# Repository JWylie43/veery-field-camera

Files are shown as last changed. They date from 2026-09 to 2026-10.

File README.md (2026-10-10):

# Veery — ROCK 5T Stereo Field Camera

A field camera for filming a whole game from the sideline: two cameras on a
**Radxa ROCK 5T** record the field in 4K, and a Mac app stitches the two views into one
wide panorama and cuts it into a normal 16:9 video you "film" afterwards with a virtual
camera.

It's a **hardware project as much as a software one**:

- **Hardware** - the board, two Raspberry Pi HQ (Sony IMX477) cameras with 110° fisheye
  lenses, the genlock wire, a 3D-printed housing: parts list, design choices and
  assembly in **[hardware/](hardware/README.md)**.
- **Software** - this repo's other half: the Rock's camera support and recorder, and
  **Studio** on the Mac (below).

```
  ROCK 5T (on the rig)                       Mac
  ──────────────────────                     ──────────────────────────────────────────
  two IMX477 cameras, genlocked              Studio (browser app, studio/)
  → recorder panel :8080                       Align  → each take's camera alignment
  → take_TS_cam0.mkv + _cam1.mkv   ──SSD──►    Stitch → one panorama (.mp4)
                                               Edit   → points + virtual camera → 16:9 video
```

> **Platforms:** the Rock runs Radxa's Debian. The Mac side (Studio, calibration) is
> **macOS / Linux only** (tested on macOS); Windows is not supported.
> This is the `radxa-rock-5t` branch; the earlier Jetson Orin Nano rig is on
> [`nvidia-orin-jetson-nano`](../../tree/nvidia-orin-jetson-nano).

---

## 1. Set up the Rock

The Rock runs our **image**: Radxa's own stock Debian image for the ROCK 5T, with
three things added - the **camera kernel** (Radxa's kernel with an IMX477 driver built
in; theirs has none), the camera **overlay and tuning**, and a few **helper services**
(the recorder panel, Wi-Fi/hotspot setup, a fix for Radxa's camera daemon). Nothing
else is changed.

1. Download **`rock5t-camera-image-N.img.xz`** from the newest `image-N`
   [release](https://github.com/JWylie43/veery-field-camera/releases) and flash it to
   an SD card or NVMe drive (**16 GB+**) with balenaEtcher or Raspberry Pi Imager.
2. *Optional - lets you set it up with no monitor, keyboard or mouse:* on the card's
   **`config`** drive (it appears on the Mac after flashing), fill in
   **`camera-network.txt`** with your Wi-Fi, so the Rock joins it on first boot and you
   can reach it from your computer. Skip it and the Rock instead starts its own hotspot,
   `VeeryCam` (password `changeme123` - join it from a phone or laptop), or plug in
   Ethernet. Either way, change the hotspot's default password: in this file, or later
   on the Rock.
3. Connect the cameras and power on. The first boot takes a few minutes.

The recorder is then at `http://veery.local:8080` at home, or - when your Wi-Fi isn't in
range - on the `VeeryCam` hotspot at `http://10.43.0.1:8080`. Log in with
`ssh radxa@veery.local` (password `radxa`; change it with `passwd`).

Details - network behaviour, updating a running Rock, setting up from Radxa's own image,
the tested versions: **[docs/rock.md](docs/rock.md)**.

## 2. Set up the Mac

```bash
brew install python cmake opencv ffmpeg     # plus Xcode's tools: xcode-select --install
git clone https://github.com/JWylie43/veery-field-camera.git && cd veery-field-camera
./setup.sh                                  # Python environment + Studio's C++ tools
```

(On Linux, install the same four with the system package manager and a C++ compiler.)
Start Studio with `studio/studio.command` (or double-click it). It opens in the browser
and works on the takes folder `~/Desktop/takes` (`--takes DIR` for another).

## 3. A game

1. **Record** - open the recorder panel, check both previews, press **Record**;
   **Stop** at the end. Each take is two files, `take_TS_cam0.mkv` + `take_TS_cam1.mkv`
   (~25 GB per hour).
2. **Offload** - plug the shuttle SSD into a blue USB 3 port on the Rock, **Manage
   Files → Copy to drive**, eject; copy the takes into `~/Desktop/takes` on the Mac.
   Copy → verify → only then delete from the Rock.
3. **Align** - in Studio, tick the new takes → **Align selected** (measures each take's
   camera alignment; the mount settles slightly between sessions).
4. **Stitch** - **Stitch →** on a take: set the crop box (and rotation / shear if
   needed) on any frame → **Stitch**.
5. **Edit** - **Edit →** on the stitched video: mark each point with **I** / **O**, then
   press **R** and steer the box with the mouse while it plays → **Render…**.

## More

| | |
|---|---|
| [hardware/](hardware/README.md) | the physical rig: parts list, design choices, assembly, housing files |
| [docs/rock.md](docs/rock.md) | the Rock: image setup, Wi-Fi and hotspot, `setup.sh`, tested versions, recording, offload |
| [docs/calibration.md](docs/calibration.md) | the base calibration and per-take alignment |
| [docs/stitching.md](docs/stitching.md) | the stitch page, checking a take, the stitcher's command line, how it works |
| [docs/editing.md](docs/editing.md) | the editor: cutting, framing, keys, rendering |
| [studio/README.md](studio/README.md) | how Studio works: pages, jobs, what a stitched video records |
| [rock5t-camera/image-build/](rock5t-camera/image-build/README.md) | building and publishing the Rock image |
| [rock5t-camera/kernel-build/](rock5t-camera/kernel-build/README.md) | building and publishing the camera kernel |
| [rock5t-camera/ROCK5T_CAMERA.md](rock5t-camera/ROCK5T_CAMERA.md) | hardware bring-up log - read before touching the driver, overlay or ISP tuning |

## Status

| Piece | State |
|---|---|
| IMX477 driver + dual-camera overlay | working - camera kernel `6.1.84-8-rk2410-imx477` ([`kernel-1`](https://github.com/JWylie43/veery-field-camera/releases/tag/kernel-1)) |
| ISP tuning | tuned (`rock5t-camera/iqfiles/`) |
| Dual 4K30 recording | working |
| Calibration | solved and refined on footage (2026-10-03); per-take alignment in Studio |
| Rock image | [`image-1`](https://github.com/JWylie43/veery-field-camera/releases/tag/image-1) - flashed and verified on the rig |
| Studio: align / stitch / edit | working |
| Open | capture bitrate (28 Mbit/s per camera) looks low for stitching - see [docs/rock.md](docs/rock.md#open-questions) |

## Project layout

```
veery-field-camera/
├── rock5t-camera/        runs ON THE ROCK
│   ├── recorder/           the recorder panel (server.py) + its service
│   ├── setup.sh            installs / updates / checks everything on a running Rock
│   ├── system/             network setup + rkaiq 3A fix (installed by setup.sh / the image)
│   ├── image-build/        builds the ready-to-flash image
│   ├── kernel-build/       builds the camera kernel
│   ├── driver/  overlay/  iqfiles/   the IMX477 driver, camera overlay, ISP tuning
│   └── reference/          vendor source material (drivers, overlays, schematic)
├── studio/               runs ON THE MAC - Studio (server.py, static/ pages, native/ C++ tools)
├── calibration/          the base calibration (calibrate.py, the board, the JSONs)
├── docs/                 the detailed guides
├── hardware/             the physical rig: parts list, design, assembly, housing/ (printable enclosure)
├── setup.sh              Mac setup (.venv + Studio's C++ tools)
└── requirements.txt      the Mac's Python packages
```

## License

See [LICENSE](LICENSE).

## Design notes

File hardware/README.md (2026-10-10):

# Hardware

The physical rig: what it's made of, why, and how it goes together. The software
(everything else in this repo) assumes this hardware - the camera driver, the overlay,
the tuning and the calibration are all specific to it.

- [Parts list](#parts-list)
- [Genlock](#genlock)
- [Design choices](#design-choices)
- [Assembly](#assembly)
- [Files](#files)

---

## Parts list

### The camera

| Part | Qty | Notes | Price | Link |
|---|---|---|---|---|
| **Raspberry Pi HQ Camera - M12 mount** (Sony IMX477) | 2 | the sensors, with an M12 lens mount built in. Ships with **three lens locking rings** (one used, two spare) and a 1/4"-20 tripod thread | $52.50 each | [Adafruit 5661](https://www.adafruit.com/product/5661) |
| **Commonlands CIL391** lens, 3.25 mm M12, 110° | 2 | fisheye, -16% barrel; ~104.5° horizontal in the 4K mode. Made for the M12 HQ Camera | $39 each | [Commonlands](https://commonlands.com/products/gopro-replacement-m12-lens) |
| **Radxa ROCK 5T** (RK3588), 8 GB | 1 | the computer: two camera connectors, hardware HEVC encoder, Wi-Fi 6 | ~$297 | [Radxa](https://radxa.com/products/rock5/5t) |
| **Radxa Heatsink 6240B** | 1 | the board's heatsink + fan (fits ROCK 5B / 5B+ / 5T) | from Radxa's partners | [Radxa](https://radxa.com/products/accessories/heatsink-6240b/) |
| **Radxa FPC cable AC008** (31-pin 0.3 mm → 15-pin 1.0 mm) | 2 | board ↔ camera | ~$9 | [Radxa](https://radxa.com/products/accessories/fpc-adapter-cable-ac008) |
| **Noctua NF-A4x10 5V** fan (40×10 mm) | 2 | housing cooling | ~$17 each | [Amazon](https://www.amazon.com/dp/B00NEMGCIA) |
| **NVMe SSD**, M.2 2280, **500 GB minimum** | 1 | system + recordings (~25 GB per hour of recording). This rig: WD Green SN350 500 GB | ~$114 | [Amazon (WD SN350 500 GB)](https://www.amazon.com/dp/B0BXVVYCRN) |
| Genlock wire | 1 | a single wire between the two cameras' **XVS** pins - see [Genlock](#genlock) | - | - |
| 3D-printed housing (top + bottom) | 1 set | [`housing/`](housing/); holds the board and both cameras at the fixed toe-in | ~$12 | print it |
| 1/4"-20 brass heat-set inserts | as needed | the mount thread in the housing | ~$11 (30-pack) | [Amazon](https://www.amazon.com/dp/B0DNQLXJHY) |

> This rig was actually built with the **C/CS-mount** HQ Camera
> ([Adafruit 4561](https://www.adafruit.com/product/4561)) plus an M12-to-CS adapter
> (from an Arducam lens kit). The M12-mount version above replaces both and holds the
> same lens directly.

### Power

| Part | Qty | Notes | Price | Link |
|---|---|---|---|---|
| **USB-C PD to DC barrel cable** (5-20 V selectable) | 1 | **set it to 15 V** for the ROCK 5T | ~$17 | [Amazon](https://www.amazon.com/dp/B0GRJC9TR1) |
| **USB-C PD power bank** | 1 | any power bank with USB-C Power Delivery output. This rig: Anker A1289 | ~$119 | [Anker A1289](https://www.anker.com/products/a1289) |

**Power path:** power bank (USB-C PD) → PD-to-DC cable, **set to 15 V** → the ROCK 5T's
DC jack.

---

## Genlock

The two cameras are **genlocked**: a single wire joins the **XVS** (vertical sync) pins of
the two sensors. One camera, cam0, drives the frame timing and the other, cam1, follows
it, so both expose every frame at the same instant: moving players line up across the
seam, and the two recordings have an exact, constant frame offset. The driver sets which
camera leads (the kernel parameter `imx477.genlock`, on by default: cam0 leads, cam1
follows).

This is **why the Raspberry Pi HQ Camera** is used: its board exposes the IMX477's XVS
signal. Smaller IMX477 modules don't break it out, and without it the two cameras would
free-run and drift apart in time.

---

## Design choices

- **ROCK 5T**: its RK3588 encodes two 4K30 HEVC streams in hardware, so the CPU stays
  near idle and the rig has thermal headroom for hours outdoors. Two camera connectors,
  one per sensor.
- **Two Pi HQ (IMX477) cameras**: well-documented sensor with a Raspberry Pi driver and
  tuning to start from; the ROCK 5T needed its own driver for it (see
  [`../rock5t-camera/`](../rock5t-camera/)). The M12-mount version takes small, light
  M12 lenses (5 g each), which keeps the two cameras close together in a compact housing.
- **110° fisheye lenses, ~75° apart**: two wide views overlapping in the middle cover a
  whole field from the sideline. The overlap is where they're stitched.
- **Genlock (XVS)**: both sensors expose at the same instant, so moving players line up
  across the seam and the two files have an exact frame offset - the reason for the HQ
  Camera (see [Genlock](#genlock)).
- **Cameras mounted upside down**: images are rotated 180° in software everywhere they
  are saved or shown (see [docs/calibration.md](../docs/calibration.md#two-facts)).
- **Fixed 4K30, 28 Mbit/s per camera**: one less thing to get wrong at a game (see the
  open bitrate question in [docs/rock.md](../docs/rock.md#open-questions)).
- **A rigid housing**: the stitch depends on the cameras' exact angles, so nothing may
  move. The mount still settles slightly between sessions, which per-take alignment in
  Studio corrects.

---

## Assembly

The points the software depends on:

1. Mount both cameras in the housing **upside down**, at the housing's fixed toe-in.
2. Connect each camera to one of the ROCK 5T's two camera connectors with an FPC cable.
3. Wire the two cameras' XVS pins together ([Genlock](#genlock)).
4. **Focus each lens and lock it:** screw a locking ring onto the lens, screw the lens
   into the camera's M12 mount until the image is sharp, then tighten the ring against
   the mount. Never turn or reseat a lens afterwards without recalibrating that camera.
5. Fit the NVMe drive, flash the Rock image (see the [README](../README.md#1-set-up-the-rock)),
   and confirm both cameras with `rock5t-camera/setup.sh --check`.
6. Calibrate the finished rig - [docs/calibration.md](../docs/calibration.md). Once per
   housing build, and again if the mount is disturbed.

---

## Files

- [`housing/`](housing/) - the enclosure, top and bottom: `.3mf` (editable) and `.stl`;
  the `PRINT ORIENTED` files are rotated for printing.
- [`../rock5t-camera/SCHEMATIC_FACTS.md`](../rock5t-camera/SCHEMATIC_FACTS.md) - the
  ROCK 5T's camera connector wiring, from Radxa's schematic.
- [`../rock5t-camera/ROCK5T_CAMERA.md`](../rock5t-camera/ROCK5T_CAMERA.md) - the hardware
  bring-up log: measured lens FOV, cable signal-integrity findings, the 4K link speed.

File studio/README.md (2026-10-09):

# Studio

One local web app for a folder of takes: **align** them, **stitch** them, **edit** the
results. It runs on the Mac and opens in the browser; nothing leaves the machine
(it listens on 127.0.0.1 only). **macOS / Linux only** (tested on macOS): the job
runner uses Unix process features (pseudo-terminals, process groups), and there is
no Windows build of the C++ tools.

```bash
studio/studio.command                       # or double-click it in Finder
studio/studio.command --takes /path/to/takes --port 8100
```

It runs with the repo's Python environment (`.venv/` at the repo root) and the two
C++ tools in `studio/native/build/`; the repo-root `./setup.sh` makes both (and
`studio.command` runs it on first use). Needs `ffmpeg`/`ffprobe` on PATH.

## Pages

| Page | What it is |
|---|---|
| `/` | The takes folder. **Camera pairs** (`take_…_cam0` + `_cam1`): tick several → **Align selected**, or a row's **Align** / **Stitch →**. **Stitched videos** (only videos Studio stitched, see below): **Edit →**. Every row shows its job's live status; **Details** has the alignment result, frame-timing check, settings and each job's full log. |
| `/stitch/<take>` | Reached from a pair's **Stitch →**. The stitch controls on that pair: any frame (slider / box, `,` `.` step), shift far/near (shear), rotation, crop box, In/Out points, output name. Loads the take's `.align.json` (rotation + default shear) or the base calibration. **Stitch** starts the job. |
| `/edit/<video>` | Reached from a stitched video's **Edit →**. The Director (cut points, steer the virtual camera). The edit autosaves next to the video (`name.director.json`, backups in `name.director-backups/`); **Render…** starts the job. |

The take or video is in the URL, so a refresh, a bookmark or a second tab all
open the same thing; nothing about "the current take" lives in the server.

## Jobs

Each align / stitch / render is **one process** - the same command you would
type in a terminal - started by the server, which keeps its output as the job's
log and turns its progress lines into a percent. The pages poll `GET /api/jobs`
(once a second); a job keeps running if you close or reload the page, and its
status shows on the takes list and on its own page.

| Job | Command | At once |
|---|---|---|
| align | `studio/refine_extrinsics.py --align <cam0>` | 2 (the rest queue) |
| stitch | `studio/native/build/StitchPipeline --source … --metadata-file …` | 1 (a second is refused) |
| render | `studio/native/build/Director --render <project> …` | 1 |

A take can't be aligned while it is stitching (or the reverse). **Cancel** stops
the process and its ffmpeg children; a cancelled stitch's partial file is removed.
Job history lives in memory - a server restart forgets it (the files it made stay).

## What a stitched video records

The stitch job writes this into the MP4's `comment` tag (JSON), which is also how
the takes list knows a video is a stitch it can edit:

```json
{ "kind": "stitch", "version": 1, "take": "take_20261003_165256",
  "sources": ["take_…_cam0.mkv", "take_…_cam1.mkv"], "stitched": "2026-10-08T20:46:00",
  "calibration": { "base": "calibration/stereo_extrinsics.json",
                   "take_alignment": "take_20261003_165256.align.json",
                   "corrections_from_base_deg": {…}, "rotation_matrix": [[…]] },
  "pairing": { "offset": 0, "method": "timestamps", "detail": "…" },
  "panorama": [6823, 2371],
  "settings": { "degrees": 0.4, "crop": [341, 119, 6141, 2134], "shift_top": -5.4,
                "shift_bottom": 15.3, "start": 3000, "end": 3059, … },
  "command": "…/StitchPipeline --source … --out-file …" }
```

Read it back with
`ffprobe -v error -show_entries format_tags=comment -of default=nw=1:nk=1 video.mp4`.
Videos stitched before Studio (or with an old StitchPipeline build without
`--metadata-file`) have no record and are not listed.

## The stitch preview

The preview is the stitcher's own warp, recomputed in Python (`rig.py` +
`preview.py`): same cylinder canvas, same fisheye model, same left/right choice,
same frame pairing (`--pair-offset` from the capture timestamps, passed to the
stitcher explicitly). Checked against StitchPipeline output: identical canvas
size and seam, alignment within 0.003 px, same frame index at any position.
It shows the plain warp - the smart seam, 6-band blend and
exposure match happen in the stitch.

## Files

```
studio/
├── server.py             the web app: pages, API, starts jobs
├── jobs.py               one process per job, run in a pseudo-terminal; progress parsers
├── library.py            scans the takes folder (pairs, stitched videos, frame-timing check)
├── preview.py            the stitch page's frames
├── rig.py                take files, calibration, pairing and the stitcher's geometry
├── refine_extrinsics.py  per-take alignment (also usable on its own, see docs/calibration.md)
├── static/               index.html (takes), stitch.html, edit.html (the Director's editor), studio.css
├── native/               the C++ tools: stitch_pipeline.cpp, director.cpp, CMakeLists.txt, include/json.hpp
├── studio.command        start Studio (Python packages: ../requirements.txt, set up by ../setup.sh)
```

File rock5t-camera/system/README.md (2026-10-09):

# system/

Files `setup.sh` installs into the Rock's system configuration.

- `camera-network.txt` → `/config/camera-network.txt` (the template, on the image only),
  with `camera-network` → `/usr/local/sbin/` and `camera-network.service`: at the next
  boot it creates the Wi-Fi connection (only with both name and password; priority 100,
  autoconnect) and the hotspot (a 2.4 GHz access point at 10.43.0.1, priority -10, open
  if it has no password, and NOT autoconnect), then renames the file
  `camera-network.applied.txt` with the passwords blanked - so it is read once.
  Re-applying replaces those two connections; others are left alone.
- `wifi-fallback` → `/usr/local/sbin/` and `wifi-fallback.service`, every boot: scans
  once; connects to the best known Wi-Fi in range, and starts the hotspot if that fails
  (wrong password) or if no known Wi-Fi is in range (or set up at all) - no fixed waits. The hotspot must not autoconnect:
  it would come up before the radio's first scan has seen the home network, and an
  access point can't scan, so it would stay up even at home.
- `rkaiq_3A-override.conf` → `/etc/systemd/system/rkaiq_3A.service.d/override.conf`.
  Radxa's `rkaiq_3A.service` is a oneshot wrapper that backgrounds `rkaiq_3A_server`;
  systemd sees the wrapper exit and runs `ExecStop` (`killall`), so the 3A daemon - the
  cameras' auto exposure / white balance, which loads the IQ tuning file - dies ~16 ms
  after it starts. This drop-in runs the daemon directly and keeps it running. (No
  comments inside it: setup.sh compares it byte for byte with the installed copy.)

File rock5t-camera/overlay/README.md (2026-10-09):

# ROCK 5T dual IMX477 overlay

`rock-5t-dual-rpi-hq-imx477.dts` enables both Pi HQ cameras with XVS genlock
roles: CAM0 connector = source (master), CAM1 connector = sink (slave). Chains
are copied verbatim from Radxa's shipped `rock-5t-cam{0,1}-radxa-camera-8m-219`
overlays (same 2-lane Sony-sensor path), sensor nodes swapped to `imx477@1a`.

`rock5t-camera/setup.sh` builds and installs this for you. By hand:

## Build (on the Rock, needs kernel headers for the dt-bindings includes)

```bash
H=/usr/src/linux-headers-$(uname -r)
cpp -nostdinc -I "$H/include" -undef -x assembler-with-cpp \
    rock-5t-dual-rpi-hq-imx477.dts \
  | dtc -I dts -O dtb -@ -o rock-5t-dual-rpi-hq-imx477.dtbo
```

(`dtc` warnings about unit names are normal; errors are not.)

## Install

```bash
sudo cp rock-5t-dual-rpi-hq-imx477.dtbo /boot/dtbo/
sudo u-boot-update       # or enable via rsetup -> Overlays
sudo reboot
```

Overlays in `/boot/dtbo/` ending in `.dtbo` are active; rename to
`.dtbo.disabled` to deactivate (same convention as the shipped overlays).

## Depends on

- the imx477 driver present in the running kernel (it is built IN,
  `CONFIG_VIDEO_IMX477=y` - see `../kernel-build/README.md`; it is NOT a
  loadable .ko). The overlay's `compatible = "sony,imx477"` and `trigger-mode`
  property are consumed by it.
- `../iqfiles/imx477_RPI-HQ_default.json` in `/etc/iqfiles/` (matched via
  `rockchip,camera-module-name = "RPI-HQ"`)

## Verify after reboot

```bash
sudo i2cdetect -y -r 3     # 0x1a = UU on i2c3 (CAM0)
sudo i2cdetect -y -r 4     # 0x1a = UU on i2c4 (CAM1)
dmesg | grep -i imx477
v4l2-ctl --list-devices    # rkcif/rkisp video nodes
```

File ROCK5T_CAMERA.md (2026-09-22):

# Raspberry Pi HQ Camera (IMX477) on the ROCK 5T

**Status: working.** Both IMX477s image through the full ISP path at 4K30 and
record to hardware HEVC. Driver is built into a custom kernel
(`6.1.84-8-rk2410-imx477`, `CONFIG_VIDEO_IMX477=y`), overlay and IQ file are
installed, intrinsics are solved. The open item is the stereo extrinsics, which
are still placeholder design values — see the README.

This file is the **bring-up log**: a dated record of what was tried, what broke
and why, kept because none of it is recoverable from the code. Newest entries
are at the bottom. For how to *run* the rig, see [README.md](README.md).

> **Resuming this work (e.g. cables arrived)? Start with
> [`NEXT_STEPS.md`](NEXT_STEPS.md)** — a self-contained handoff: current state,
> how to operate the board, and the exact next-step sequence.

Goal: run the two genlocked Pi HQ cameras on the **Radxa ROCK 5T** (RK3588).
Three deliverables, none of which exist today: a **kernel driver**, a
**device-tree overlay**, and an **ISP tuning (IQ) file**. The XVS genlock
validated on the Orin (see `RPI_HQ_CAMERA.md`) is sensor-side and ports
straight into the new driver.

## Board recon (2026-09-03, live from the device)

| Item | Found |
|---|---|
| Board | Radxa ROCK 5T (`/proc/device-tree/model`) — NOT the 5B+ the flex adapter targeted; verify camera connectors before ordering cables |
| OS / kernel | Debian 12, vendor kernel `6.1.84-8-rk2410` |
| Kernel headers | installed (`linux-headers-6.1.84-8-rk2410`) → out-of-tree module builds work on-device |
| Build tools | gcc, make, git all present |
| ISP stack | `camera-engine-rkaiq 6.8.0-rk3588`, matches **rkisp v30** → that's the IQ JSON schema to target |
| IQ files | `/etc/iqfiles/` has imx219 (RPi cam v2), ov5647 (RPi cam v1), imx415 4K, others — **no imx477** |
| Camera drivers | built into the kernel (`=y`, not modules): imx219, imx415, imx464, imx214, **imx577** |
| IMX477 driver | none, anywhere |
| Overlays | `/boot/dtbo/` all generic/disabled; radxa-overlays source has camera overlays only for CM3-series boards — none for 5B/5T |
| Overlay management | `rsetup` (Radxa's tool) + `/boot/dtbo/` |
| `/dev/video0` | `stream_hdmirx` (the 5T's HDMI input — not a camera) |

## Why this is tractable

1. **`CONFIG_VIDEO_IMX577=y`** — Rockchip's vendor kernel already carries a
   driver for the IMX577, the IMX477's near-identical sibling (same 12.3MP
   Sony family). The IMX477 driver should be a light adaptation of that code
   (chip-ID, mode tables), not a from-scratch port. Rockchip sensor drivers
   also carry the RKMODULE ioctls the rkisp/rkaiq stack uses to find the
   right IQ file — mimic imx577/imx415, don't transplant the RPi driver.
2. **Radxa already tunes RPi cameras** (v1/v2 IQ files ship in the image), so
   RPi-camera-on-Rock is a trodden path — just not yet for the HQ camera.
3. **RPi publishes the IMX477's lab calibration** (`imx477.json` in the
   libcamera/raspberrypi repos): black level, noise-vs-gain model, AWB CT
   curve, CCMs at ~8 color temperatures, gamma. The IQ file is a translation
   into the rkisp v30 JSON, not a re-measurement.

## Bring-up log (2026-09-04): software stack VALIDATED on hardware, awaiting cameras

First install on the actual ROCK 5T (kernel 6.1.84-8-rk2410) — everything
that can be proven without cameras is proven:

- **Driver compiles clean** first try against the installed headers (only the
  cosmetic Debian gcc point-release warning); `imx477.ko` vermagic matches the
  running kernel; `trigger_mode` + `dpc_enable` params present.
- **Overlay compiles** (only cosmetic graph_child_address warnings) to a 10.5KB
  dtbo. Activated via `u-boot-update` (this image retired uEnv.txt; overlays =
  every non-`.disabled` *.dtbo in /boot/dtbo/, baked into extlinux.conf's
  `fdtoverlays` line).
- **After reboot:** overlay applied — both chains live (`rkcif-mipi-lvds2` +
  `rkcif-mipi-lvds4`) and **both** ISP mainpaths registered (`rkisp0-vir0`
  video22-28, `rkisp1-vir1` video31-37). Driver auto-loaded via modalias,
  bound BOTH nodes (`imx477 3-001a`, `imx477 4-001a`), fell back gracefully on
  the absent reset/pwdn GPIOs + regulators (Pi HQ self-powers — by design),
  reached the chip-ID read and reported `Unexpected sensor id(0000), ret(-5)`
  on both buses — the correct "no sensor connected" signal.

**Install steps that worked** (from ~/veery-field-camera/rock5t-camera):
```
cd driver && make && sudo cp imx477.ko /lib/modules/$(uname -r)/kernel/drivers/media/i2c/ && sudo depmod -a
sudo cp iqfiles/imx477_RPI-HQ_default.json /etc/iqfiles/
cd overlay && H=/usr/src/linux-headers-$(uname -r); cpp -nostdinc -I "$H/include" -undef -x assembler-with-cpp rock-5t-dual-rpi-hq-imx477.dts | dtc -I dts -O dtb -@ -o rock-5t-dual-rpi-hq-imx477.dtbo
sudo cp rock-5t-dual-rpi-hq-imx477.dtbo /boot/dtbo/ && sudo u-boot-update && sudo reboot
```

**At cable time**, expected success: `imx477 N-001a: ... sensor id 0x0477`,
probe succeeds, `i2cdetect -y 3` / `-y 4` show `UU` at 0x1a, video pipeline
completes. Then: `v4l2-ctl` raw smoke test -> rkaiq/ISP path (uses the IQ
file) -> port sync_test.sh for genlock. If probe still reads 0000 WITH a
camera attached, suspect cable/connector seating first, then the RPi-HQ R8
power-down issue (see rpi-hq-camera-orin memory / RidgeRun).

## Bring-up log (2026-09-11): cameras cabled — probe PASSES, async-bind race found + fixed

Both Pi HQ cameras connected (CAM0 J5002, CAM1 J10) with the new 30-pin cables.

- **STEP 2 PASS:** `Detected Sony imx0477 sensor` on `3-001a` AND `4-001a`;
  `i2cdetect` shows `UU` at 0x1a on buses 3 and 4. Cables, wiring, overlay
  chains, driver probe: all good. No R8 power-down issue.
- **New blocker found: module load-order race.** The sensor entities never
  appeared in the CIF media graphs (`csi2-dphy0/4` sink pads unlinked), so
  rkaiq found no camera (and segfaulted — it crashes on an empty sensor list)
  and mainpath STREAMON returned EPERM (`check rkisp_mainpath link or isp
  input`). Root cause, from dmesg timeline + vendor `phy-rockchip-csi2-dphy.c`:
  the D-PHY registers its sensor async-notifier at probe (~11.8s), and at
  ~11.87s rkcif/rkisp run Rockchip's **"clear unready subdev"** — dropping the
  not-yet-arrived sensor and force-completing the notifiers. Out-of-tree
  `imx477.ko` loads via udev at ~14.5s: registers fine, matches nothing, ever.
  Radxa's own cameras never hit this because their sensor drivers are **built
  into the kernel** (`=y`) — only an out-of-tree sensor module can lose this
  race. (Phandle fixups, DT graph, CONFIG_NO_GKI, driver binding: all verified
  fine along the way.)
- **Dead end, do not retry:** unbind/rebind of `csi2-dphy0` at runtime → kernel
  oops (vendor rkcif/rkisp keep stale refs into the D-PHY after notifier
  completion). Reboot required after any such attempt.
- **Load-order fixes that DON'T work (tried, keep for the record):** modprobe
  softdep (parsed but never honored) and /etc/modules-load.d early static load
  (userspace itself starts too late). Root reason found by timeline + vendor
  source: the whole pipeline (dphy/csi2/cif/isp) is **builtin** (the .ko-looking
  entries are in modules.builtin), it probes during kernel init, and the
  "clear unready subdev" pass is a **late_initcall** — it runs BEFORE
  `Run /init` (11.98s vs 11.99s on this image). The vendor clear
  (`v4l2_async_notifier_clr_unready_dev`, CONFIG_NO_GKI) permanently
  `list_del`s the pending sensor asd, so a later registration matches nothing.
  **No module load ordering can ever win this race. The design assumes sensor
  drivers are builtin (Radxa's all are `=y`).**
- **Fix that works — split enable (now the required install):** the boot
  overlay leaves the ten v4l2 pipeline nodes disabled (nothing camera-related
  exists for the boot-time clear to purge); after boot,
  /etc/modules-load.d loads `imx477` then `rk_cam_defer_enable.ko`
  (driver/), which applies `overlay/rock-5t-cam-runtime-enable.dts` (installed
  as /lib/firmware/rock5t-cam-enable.dtbo) via `of_overlay_fdt_apply()`
  (EXPORT_SYMBOL_GPL; CONFIG_OF_OVERLAY=y on this kernel, no OF_CONFIGFS).
  The builtin drivers then probe with the sensors already registered.

  ```
  cd driver && make && sudo make install       # builds+installs both .ko
  cd ../overlay && dtc -I dts -O dtb -o rock5t-cam-enable.dtbo rock-5t-cam-runtime-enable.dts
  sudo cp rock5t-cam-enable.dtbo /lib/firmware/
  # rebuild + reinstall the boot dtbo (same cpp|dtc command as above)
  printf "imx477\nrk_cam_defer_enable\n" | sudo tee /etc/modules-load.d/imx477.conf
  sudo reboot
  ```

  Success signature after reboot: `rk_cam_defer_enable: applied ...`,
  `dphy0 matches m00_b_imx477 3-001a` (and dphy4/m01) in dmesg;
  `m0x_b_imx477` entities present in media graphs.
  **DKMS packaging must ship both modules, the runtime dtbo, and the
  modules-load.d file.**
- **Also found:** `rkaiq_3A.service` is broken as shipped (oneshot wrapper
  backgrounds the server, systemd then runs ExecStop = `killall`, so it dies
  after ~16ms). Run `sudo rkaiq_3A_server` manually for now; fix the unit
  (RemainAfterExit=yes or Type=forking) before relying on it.
- **Topology note for STEP 3:** this stack runs CIF→ISP **online** — the rkcif
  video nodes are not for raw capture here; the smoke test goes through
  `rkisp_mainpath` (video22 = CAM0, video31 = CAM1, NV12) with rkaiq_3A_server
  running. The raw-bypass grab in NEXT_STEPS STEP 3 doesn't apply as written.

## Bring-up log (2026-09-11, later): PIPELINE COMPLETE on custom builtin-driver kernel

The stock-kernel workaround attempts (see the earlier 2026-09-11 entry) kept
hitting new vendor races, so Joe chose the kernel route:
`kernel-build/build-kernel.sh` clones radxa/kernel **linux-6.1-stan-rkr4.1**
(= 6.1.84, matching the shipped 6.1.84-8-rk2410; rkr1 is 6.1.43 — wrong),
injects the driver in-tree, sets CONFIG_VIDEO_IMX477=y on the stock config,
and builds debs. Built in ~6 min in an arm64 Debian docker container on the
Mac M5 Pro (vs 1-2h native on the Rock) — container flow: clone in container
FS (not a bind mount), copy in /boot/config-* from the Rock + imx477.c,
`make -j18 bindeb-pkg LOCALVERSION=""`, docker cp the debs out, scp to Rock,
dpkg -i + u-boot-update (stock kernel remains the boot-menu fallback).

**First boot of 6.1.84-8-rk2410-imx477: complete success.** Sensors detect at
11.83s (kernel init), `dphy0 matches m00_b_imx477` / `dphy4 matches
m01_b_imx477`, and ALL FOUR notifiers complete (rkcif-mipi-lvds2/4 AND
rkisp0-vir0 / rkisp1-vir1 — the ISPs never completed on any stock-kernel
attempt). Full-enable overlay, zero runtime workarounds.

## Bring-up log (2026-09-11, night): FIRST LIGHT — both cameras imaging through the full ISP path

- rkaiq_3A fixed as a boot service (systemd drop-in, see kernel-build/README).
- Driver rev-2 (`trigger_mode` runtime override) built + installed; with the
  XVS pads not yet wired, `echo 0 > /sys/module/imx477/parameters/trigger_mode`
  free-runs both cameras (DT roles stay source/sink for genlock day).
- Both cameras capture clean 1080p NV12 from the mainpaths (video22/video31),
  steady at 10 fps = the sensor's default full-res 4056x3040@10 mode; the ISP
  scales. **4K30 mode selection is still TODO** (bake into record_dual.sh).
- **First-light images: sharp, detailed, correct geometry (inverted — cameras
  physically upside down), same scene from offset positions = stereo pair
  working.** Quality issues match the IQ TRANSLATION_NOTES predictions
  exactly: strong blue cast (AWB regions are imx577-module values — the
  flagged first recalibration) and dark indoors (8ms sports shutter cap +
  evening room light + aperture). Tune AWB via gen_imx477_iq.py in daylight;
  don't hand-edit the json.
- Grab-a-frame recipe: v4l2-ctl 60 frames to /tmp/*.nv12 (last frames are
  AE-converged), then
  `ffmpeg -f rawvideo -pix_fmt nv12 -s 1920x1080 -i X.nv12 -update 1 X.png`.

## Bring-up log (2026-09-11, late): sensor modes proven; 4K30 has CRC noise, binned is clean

- Mode switching works: set the sensor subdev fmt, then **restart rkaiq_3A**
  before streaming (stale 3A state after a mode change = zero frames).
  `SENx=$(media-ctl -d /dev/mediaN -e "m0X_b_imx477 ...")` then
  `v4l2-ctl -d $SENx --set-subdev-fmt pad=0,width=W,height=H,code=C`
  (0x3012=SRGGB12 for full/binned, 0x300f=SRGGB10 for 4K30).
- **2028x1520@40 binned: flawless** (40.00fps, 25ms cadence, zero errors,
  900Mbps). This is the working recording mode today.
- **3840x2160@30: streams on BOTH cameras but with ~5k CSI CRC errors per
  30-frame burst (~7% of lines), near-identical counts on both cables →
  systematic, not one bad cable.** Candidate causes: cable/adapter SI margin
  at 2.1Gbps, or rkisp/dphy hs-settle timing for the 2096Mbps rate (software,
  affects both equally — check before buying cables). A still frame looks
  visually clean — CIF appears to absorb/drop damaged data; measure real
  delivered fps + motion artifacts before trusting 4K30.
- AWB: strong blue cast, as predicted (imx577 detection zones). Fix =
  daylight iteration session on gen_imx477_iq.py's AWB section (regenerate →
  /etc/iqfiles → restart rkaiq_3A → recapture; ~1min/iteration). Note: RPi's
  published AWB data cannot be converted to rkaiq's detection-zone format
  analytically — the zones live in rkaiq's own stats space (hence the
  imx577 placeholders).

## Bring-up log (2026-09-12): 4K30 CRC SOLVED — link re-clocked 2096 -> 1600Mbps/lane

Driver 4K30 mode re-clocked (kernel deb rev 3): IOP PLL 24/3*200 = 1600Mbps/lane
(800MHz link), hts 9024->11200 (per-line burst 1.44Gbps sustained, 11%
headroom), vts 3102->2500 (exactly 30.00 fps), MIPI global timing set to
sensor-auto (0x0808=0; the nv manual values were 2096-specific). First boot:
**data_rate 1600, 300/300 frames at 30.00 fps, ZERO CRC errors** (was
thousands at 2096 — cable SI margin, both cables identically). 4K30 is now
fully clean on the existing 30-pin FFC/adapters. Also validated this session:
Evbias -1.2 (accidental imx577 inheritance) -> 0; recording pipeline
(io-mode=dmabuf + queue) = timing-clean 4K30 H.265 recordings, all baked
into record_dual.sh.

## Bring-up log (2026-09-13): IQ texture round 1 VALIDATED; encoder bitrate root-caused

- Outdoor daylight eval (first fog was literally the window glass — shoot in
  open air). Baseline 1:1 crops: grass smeared to watercolor (spatial NR at
  full strength at base ISO) + sharpening halos (imx577 sharp_ratio=15).
- Round 1 (gen sec. 9): ynr/bayer2dnr low-ISO x0.5, cnr x0.6, sharp_ratio->6
  (ISO<=200 full, 400 tapered), dehaze+DRC disabled (scene-adaptive = pano
  seam poison). **A/B verdict: grass blades fully resolved, car edges crisp
  with zero halos. Round 1 stands.** Open round-2 candidate: shadows now run
  deep (honest tone without adaptive DRC) — judge on midday footage whether
  to add a small STATIC shadow lift via gamma.
- Encoder bitrate: mpph265enc silently ignores bps when caps carry no
  framerate (rkisp never advertises one) — 385-691Mbps files on detailed
  content; earlier in-spec files were just cheap dark scenes. Fix (verified
  27.4M vs 28M target): videorate ! framerate=N/1 before the encoder +
  rc-mode=cbr. In record_dual.sh.
- Tuning capture protocol: per scene, (1) pure video pipeline (true 30fps;
  a tee'd PNG branch starves the dmabuf pool and videorate then pads dups),
  (2) separate v4l2-ctl 90-frame burst -> last-frame PNG for pixel judgment.

## Bring-up log (2026-09-13, later): AE setpoint raised — CAPTURE-TIME CHECKLIST COMPLETE

Midday measurement: skeleton DySetpoint 16-20% (dropping when bright) left
sunny frames at mean 44/255 with only 0.25% clip = a wasted stop of headroom
(8-bit post-lifts cost quality). Raised to 26-30 (~+0.7EV): measured mean
44->62, crushed shadows 33%->11%, clip UNCHANGED 0.27%. Verified visually.

**Capture-time (unrecoverable) items now all handled:** highlight clipping
safe with margin; exposure target correct at capture; NR/sharpening mild
(post-safe direction) and validated; tone static (adaptive dehaze/DRC off —
shadow lift is now a Resolve slider, identical on both cams); WB locked
(uniform cast = one-slider post fix); bitrate honored; frame timing clean.
Shadow-lift question CLOSED by use-case: open field = only player shadows,
sunny or overcast — no deep-shade content; static tone + post grading covers
it. Field-side controls remaining: lens aperture + focus rings only.
Still open (not IQ): motion-blur/temporal-NR check on real moving subjects
(needs a motion video), LSC flat-field calibration, re-mount, XVS + sync.

## Bring-up log (2026-09-13, evening): lens HFOV MEASURED — 74° rig geometry validated

Wall measurement (Commonlands CIL391 3.25mm, 4K mode 3840 crop): W=83in at
D=29in -> **HFOV = 110.1° (+/-1.5°)**. With the 74° camera separation:
**~36° stitch overlap, ~184° total pano span** — the rig geometry closes
with margin. (Spec chain predicted 110-113°; old calibration jsons are the
1920x1200 Arducam rig — recalibrate intrinsics on these cameras before
stitching, with a strong-distortion model: lens is -16% TV barrel.)

Also found: **rkisp selfpath (video23) can hold a stale 1920x1080 crop
window instead of scaling** — preview showed a quarter of the scene 1:1
(and binned-mode recordings route via selfpath: set the crop selection
explicitly or verify FOV). Live preview workaround: stream MAINPATH
(video22) 4K->h264 10fps via udpsink to ffplay on the Mac. TODO: package
as preview.sh; add selfpath selection reset to record_dual.sh.

## Bring-up log (2026-09-18): intrinsics solved + FIRST DUAL 4K30 RECORDING

- **Intrinsics done** (cameras loose, focus locked): the CIL391 needs the
  FISHEYE model - the rational/pinhole fit leaves a uniform ~2.6px residual
  (model mismatch, FOV readout degenerates). cv2.fisheye: **RMS 0.233px
  (cam0) / 0.240px (cam1)**, f 2104/2108px (matched to 0.2%), FOV
  104.5x58.8 deg, 98% frame coverage, 46 views each. Per-unit decenter
  measured: cam0 cx 49px left (explains the asymmetric-baseboard look),
  cam1 cy 148px low - normal M12 tolerance, now calibrated rather than
  assumed. Saved: calibration/cam{0,1}_intrinsics.json.
  Board: charuco_board.png on a TV, 78mm squares (measured on glass).
  **Never touch the focus rings or reseat a lens** without recalibrating
  that camera.
- **calib_server.py / veery_server.py**: browser panels (8081 calibration,
  8080 recorder). Rules baked in: previews run CONTINUOUSLY on the selfpath
  and are never stopped/restarted (a camera switcher that restarted
  pipelines caused a lockup), snapshots/records come off the mainpath so
  both coexist, preview children run in their own process group and are
  killed on exit (orphans otherwise hold the nodes and silently black the
  next run), and startup refuses to run on top of leftovers.
- **FIRST SIMULTANEOUS DUAL 4K30 RECORDING (passed):** both cameras 238
  frames / 7.90s / **30.000 fps, zero gaps**, 27.3 + 27.2 Mbit vs the 28M
  target, clean decode. Two independent MKVs by design (fault isolation;
  the stitcher pairs full-res frames by timestamp).
- Browser note: Chrome can refuse LAN panels entirely
  (ERR_ADDRESS_UNREACHABLE) when a planted `LocalNetworkAccessAllowedForUrls`
  policy turns on Local Network Access enforcement. Safari is unaffected.

## Access
- SSH from the Mac: `ssh rock` (radxa@192.168.86.136, key auth works).

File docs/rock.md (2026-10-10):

# The Rock: setup, network, recording, offload

Everything that runs on the ROCK 5T. Quick start is in the [README](../README.md);
this is the detail.

- [Set up a Rock from the image](#set-up-a-rock-from-the-image)
- [Wi-Fi and hotspot](#wi-fi-and-hotspot)
- [Set up from Radxa's image, or update a running Rock](#set-up-from-radxas-image-or-update-a-running-rock)
- [Tested setup](#tested-setup)
- [Recording](#recording)
- [Offload](#offload)
- [Open questions](#open-questions)

---

## Set up a Rock from the image

1. Download `rock5t-camera-image-N.img.xz` from the newest `image-N` in this repo's
   [Releases](https://github.com/JWylie43/veery-field-camera/releases). Needs a **16 GB or larger** SD card or NVMe drive.
2. Flash it with any image flasher (balenaEtcher, Raspberry Pi Imager), or from
   Terminal: `diskutil unmountDisk /dev/diskN`, then
   `xz -dc rock5t-camera-image-N.img.xz | sudo dd of=/dev/rdiskN bs=4m` (check the
   disk number with `diskutil list` first - it erases that disk). A built-in Mac SD
   reader shows as an *internal* drive, which Etcher hides unless you tick "show
   hidden".
3. When it's done the card's small **`config`** partition shows up on the Mac like a
   USB stick (re-insert the card if it doesn't; if macOS offers to initialise a disk
   it can't read, click *Ignore* - those are the Linux partitions). Fill in
   **`camera-network.txt`** on it - see [Wi-Fi and hotspot](#wi-fi-and-hotspot).
4. Connect the cameras and power on. The first boot takes a few minutes: Radxa's
   first-boot setup creates the `radxa` user (password `radxa` - change it with
   `passwd`), makes the Rock's own SSH keys, grows the system partition to fill the
   drive, and enables SSH when no screen is connected; then the rig's networks are set
   up and the recorder starts.
5. The recorder is at `http://<rock-ip>:8080` (or `http://veery.local:8080`). SSH in
   (`ssh radxa@veery.local`) and confirm everything:

   ```bash
   ~/veery-field-camera/rock5t-camera/setup.sh --check
   ```

After a reflash the Rock has new SSH keys, so your Mac refuses to connect until it
forgets the old ones: `ssh-keygen -R veery.local` (and any other name or IP you use
for it).

The image is Radxa's stock image with the camera kernel, overlay, IQ tuning, 3A fix,
network setup, recorder and a git checkout of this repo (in `~/veery-field-camera`)
already installed. `/etc/camera-rig-image` records what it was built from. How it is
built and published: [rock5t-camera/image-build/](../rock5t-camera/image-build/README.md).

---

## Wi-Fi and hotspot

`camera-network.txt`, on the image's `config` partition:

```
WIFI_NAME="Gilly's Garden"     # a network to join: home, club... (quotes for spaces)
WIFI_PASSWORD="..."
HOTSPOT_NAME="VeeryCam"        # the Rock's own network, for the field (default)
HOTSPOT_PASSWORD="..."         # default changeme123 - change it; blank = an OPEN hotspot
```

The first boot reads it **once** and sets up NetworkManager:

- **Wi-Fi** - only when both `WIFI_NAME` and `WIFI_PASSWORD` are filled in (priority
  100).
- **Hotspot** - whenever `HOTSPOT_NAME` is set (default `VeeryCam`, password
  `changeme123` - the same on every image, so change it): a 2.4 GHz network the Rock
  creates itself, the Rock at `10.43.0.1`. Join it from a phone or laptop and open
  `http://10.43.0.1:8080` (SSH: `ssh radxa@10.43.0.1`). With `HOTSPOT_PASSWORD` blank
  it is **open**: anyone nearby can join and use the recorder panel. Blank
  `HOTSPOT_NAME` = no hotspot.

At **every boot** the Rock scans once: if a known Wi-Fi network is in range it connects
to it, and if that fails (wrong password) it starts the hotspot; if none is in range
it starts the hotspot **right away** - in the field a phone can join ~20 s after
power-on. With no Wi-Fi set up it starts the hotspot straight away (or use Ethernet,
which configures itself).

- **Change the hotspot password** on a running Rock (e.g. if you kept `changeme123`):
  `sudo nmcli connection modify VeeryCam wifi-sec.psk "<new password>"` - it applies the
  next time the hotspot starts.
- The Rock never joins other networks on its own, open or not.
- Networks added later with `sudo nmtui` count as known Wi-Fi too (priority 0 unless
  you set otherwise: `sudo nmcli connection modify "<name>" connection.autoconnect-priority <n>`).
- Once the hotspot is up the radio is busy being an access point, so the Rock looks
  for the Wi-Fi again at the next boot (or: `sudo nmcli connection up "<name>"`).
- After applying, the file becomes `camera-network.applied.txt` with the passwords
  blanked (they're kept on the Rock, not on the card). To apply new settings later,
  put a filled-in `camera-network.txt` back on the `config` partition (on the Rock:
  `/config/`) and reboot, or use `sudo nmtui`.
- What happened at boot: `sudo journalctl -b -u camera-network -u wifi-fallback`.

How it works: [rock5t-camera/system/](../rock5t-camera/system/README.md).

---

## Set up from Radxa's image, or update a running Rock

`rock5t-camera/setup.sh` does on a running Rock what the image has pre-installed. Use
it to **update** a Rock after `git pull` (a new kernel release, tuning, recorder), or
to turn a stock Radxa image into the rig:

```bash
git clone https://github.com/JWylie43/veery-field-camera.git && cd veery-field-camera
rock5t-camera/setup.sh            # installs what's missing, then asks to reboot if needed
rock5t-camera/setup.sh --check    # check only, change nothing
```

It installs, skipping whatever is already done:

1. **packages** - GStreamer, ffmpeg and tools (apt);
2. **the camera kernel** - Radxa's kernel with the IMX477 driver built in (stock
   kernels have none), from this repo's `kernel-N` release; installed beside the stock
   kernel, which stays in the boot menu as a fallback; kernel packages are held so a
   Radxa update can't replace it;
3. **the camera overlay** - tells the board both cameras are attached and which one
   leads the genlock;
4. **the IQ tuning file** the 3A daemon (auto exposure / colour) loads;
5. **a fix for Radxa's `rkaiq_3A.service`**, which as shipped kills the 3A daemon right
   after starting it; and the services that apply `camera-network.txt` (not the file
   itself - copy `rock5t-camera/system/camera-network.txt` to `/config/`, fill it in
   and reboot to use it on a Rock set up this way);
6. **the recorder service** - the web panel, started at every boot (only restarted if
   it changed, so a take in progress isn't cut).

Then it asks to reboot if the kernel, overlay or tuning changed, and otherwise runs its
checks: kernel and boot default, Radxa's camera software versions, tools and GStreamer
elements (including the Rockchip hardware encoder), driver and both sensors, the two
ISP nodes, the 3A daemon, the recorder, storage. `--yes` reboots without asking. It
never flashes anything, and doesn't set the hostname (this rig's is `veery`, hence
`veery.local`).

---

## Tested setup

The image is built on exactly this. Setting up from Radxa's image, flash the same one:
the camera kernel is built from that image's kernel source, Radxa's camera software (3A
daemon, hardware encoder) has to match it, and the IQ file is written for that rkaiq
version's format. `setup.sh --check` warns if a Rock's camera software differs.

| | Version |
|---|---|
| Radxa OS image | ROCK 5T Debian 12 (bookworm) KDE, release `rsdk-r7` (2026-07-06) - mirrored unmodified as this repo's release [`radxa-rsdk-r7`](https://github.com/JWylie43/veery-field-camera/releases/tag/radxa-rsdk-r7) (Radxa's original: [radxa-build/rock-5t](https://github.com/radxa-build/rock-5t/releases/tag/rsdk-r7)) |
| Kernel | `6.1.84-8-rk2410-imx477` (release [`kernel-1`](https://github.com/JWylie43/veery-field-camera/releases/tag/kernel-1)), from Radxa's `6.1.84-8-rk2410` |
| 3A daemon / ISP tuning | `camera-engine-rkaiq` 6.8.0-rk3588 |
| Hardware encoder | `librockchip-mpp1` 1.5.0-1, `gstreamer1.0-rockchip1` 1.14-4, `libv4l-rkmpp` 1.7.0-1 |
| Boot | `u-boot-menu` 4.2.2, `u-boot-rock-5t` 2017.09-64-455bd2a, `rsetup` 0.4.27 |

The recorder needs no pip packages - `recorder/server.py` is Python 3 standard library
only, on purpose. The hardware bring-up (driver, overlay, kernel, tuning) is recorded in
[rock5t-camera/ROCK5T_CAMERA.md](../rock5t-camera/ROCK5T_CAMERA.md).

---

## Recording

The recorder starts by itself at every boot (`recorder.service`). Its panel:

- two live previews (continuous, ISP selfpath, 1080p/5 fps)
- one **Record** button - starts both cameras, writes two MKVs (`take_TS_cam0.mkv` +
  `take_TS_cam1.mkv` in `~/recordings`)
- **Manage Files** - browse takes, mount/copy to the shuttle SSD, delete
- `/calib` - calibration snapshots (see [calibration.md](calibration.md))

Both cameras are recorded by ONE GStreamer pipeline (`rkisp mainpath → videorate →
mpph265enc → matroskamux`): one clock, so genlocked frames carry the same timestamps in
both files, each file keeps its first frame's real start time, and both are tagged
`shared-clock` - Studio and the stitcher read the frame offset between them exactly.
The trade-off, chosen deliberately: a fault in one camera ends the whole take. Previews
run on the *selfpath* and recording on the *mainpath*, so previews keep running during
a take; Stop sends SIGINT → GStreamer EOS → a finalized, seekable file.

The sensor mode and bitrate are **fixed** - 4K30 (3840×2160), HEVC CBR, 28 Mbit/s per
camera (~25 GB/hr for the pair, ~32 GB for a 75-minute game). No audio, by design.

**The clock.** The Rock has no clock battery: powered off it forgets the time, and at
boot it restarts from the last time it saved (its last internet sync or clean shutdown).
At home it then corrects itself from the internet. In the field there is none, so the
recorder panel fixes it: opening the panel on a phone (or any device) sends that
device's time, and the Rock takes it - only when it hasn't synced from the internet,
isn't recording, and is more than 2 s off. The panel then shows "Rock clock set from this
device". So: **open the panel before the first take** and the take names get the right
date and time.

Only one process can hold a camera node: to run anything else against the cameras, stop
the recorder first - `sudo systemctl stop recorder` (`start` to bring it back; logs:
`journalctl -u recorder -f`). By hand: `sudo python3 rock5t-camera/recorder/server.py`.

---

## Offload

**From the panel (preferred):** plug the shuttle SSD into a **blue USB 3 port** →
**Manage Files** → mount the drive → select takes → **Copy to drive**. It runs `rsync`
with progress and byte-size verification, then lets you eject. Copies land in
`<drive>/rock-recordings/`. Copy and delete are refused while recording.

**Over the network**, from the Mac:

```bash
rsync -avP radxa@veery.local:'/home/radxa/recordings/take_YYYYmmdd_HHMMSS_cam*.mkv' ~/Desktop/takes/
```

**By hand on the Rock:**

```bash
lsblk -f                                    # find the partition
sudo mount /dev/sda1 /mnt/usb
sudo rsync -avh --progress /home/radxa/recordings/take_YYYYmmdd_HHMMSS_cam*.mkv /mnt/usb/rock-recordings/
ls -l /home/radxa/recordings/take_YYYYmmdd_HHMMSS_cam0.mkv /mnt/usb/rock-recordings/take_YYYYmmdd_HHMMSS_cam0.mkv   # sizes must match
sync && sudo umount /mnt/usb                # wait for the prompt: then it's safe to unplug
```

**Golden rule: copy → verify → only then delete.** A full drive mid-recording produces
an unfinalized, non-seekable MKV - keep headroom (`df -h /home/radxa`).

---

## Open questions

**Capture bitrate looks low.** 28 Mbit/s per camera at 4K30 is ~0.11 bits/pixel. The
stitcher's own target for its HEVC *output* is ~0.20 bpp (from VMAF runs: good H.264 at
~0.26 bpp, HEVC ~40% better), so the capture master - de-warped, stitched and
re-encoded afterwards - runs at about half that, on high-entropy content (grass,
motion). Matching 0.20 bpp would be ~50 Mbit/cam (~45 GB/hr for the pair). Worth an A/B
on real footage before a real game.

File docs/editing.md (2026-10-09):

# Editing: points and the virtual camera

The editor (the **Director**) turns the full-width panorama into a normal 16:9 video:
you cut the game into points, then steer a "camera" box over each point while it plays.
Quick start is in the [README](../README.md).

On Studio's takes list, a stitched video's **Edit →** opens it in the editor
(`/edit/<video>`). The edit saves itself within a second of every change, next to the
video as `name.director.json` (reopen it to resume), with timestamped backups (at most
one per 5 minutes, the last 20) in `name.director-backups/`.

## 1 · Cut

Play or scrub, press **I** where a point starts and **O** where it ends. Points show as
bars on the timeline, numbered in game order; only they end up in the output. Points
can't overlap. Select a point to relabel it, move its In/Out to the playhead, or delete
it.

## 2 · Frame

Select a point and press **R**: playback starts 3 s before the In (pre-roll, to line up
the box), recording runs from In to Out by itself, then stops.

- The box follows the mouse left/right with its bottom on a fixed line; hold **Shift**
  to move it up/down too.
- It starts at the output size: zoom **1.00× = 1:1**, the sharpest framing (below 1 is
  wider and still sharp, above 1 is upscaled and soft - the readout under the video
  shows which).
- **Scroll** zooms ~4% per notch (**Alt** finer, **−**/**=** 2% steps); **0** or
  double-click resets to 1:1; **Shift+0** jumps to the widest full-height box.
  Scrolling out past that (it stops there once first) goes wider still: the box gets
  taller than the panorama and the output is letterboxed, up to the full panorama width.
- One take covers the whole point; **Esc** abandons a take in progress.

**Takes are protected:** recording is never undone by **Cmd/Ctrl+Z** (undo covers only
adding / deleting / moving points, and asks before removing a point that has a take).
Re-recording, clearing or trimming keeps the old take in the point's history -
**↺ Previous take** brings it back. Shortening a framed point trims its take; lengthening
it marks the point *needs re-take*.

Each take is smoothed after recording - jitter and small back-and-forths removed, the
path following your general movement without lag. Two sliders per point adjust it
(**Smoothing** = how much, **Steady** = how big a wiggle is ignored); they re-smooth
without re-recording.

**V** switches to the big output view; **P** previews the selected point as it will
render; **Preview all** plays every point back to back. **?** lists every key.

## Render

**Render…** writes one video with the points in order, or one file per point
(`name_01_Point_1.mp4`, …), at the chosen output size (1440p default), saved in the takes
folder. It runs as a Studio job - you can leave the page; progress shows on the takes
list too.

- Quality: **H.264 high** (default, plays everywhere), **HEVC high** (same quality,
  ~20% smaller) or **H.264 standard** (smaller, slightly softer).
- Unframed points are left out by default (or rendered as a full-height wide shot).
- Frames stay in the panorama's own YUV from decode to encode (no colour conversion) and
  are scaled bicubically with anti-aliasing, so a 1:1 box is a bit-exact crop before
  encoding.
- With a ~1700 px tall panorama a full-height box is ~3000 px wide, so 1440p has ~1.18×
  zoom before it upscales (1080p: ~1.57×).

The render is the `Director` command-line tool, which also runs by hand:

```bash
studio/native/build/Director --render take.director.json --out game_edit.mp4 [--per-point] \
    [--unframed skip|wide] [--codec h264|hevc] [--quality high|standard]
```

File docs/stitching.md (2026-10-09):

# Stitching

Turning a take's two camera files into one panorama. Quick start is in the
[README](../README.md); Studio itself is described in [studio/README.md](../studio/README.md).

- [In Studio](#in-studio)
- [Check a take](#check-a-take)
- [The command line](#the-command-line)
- [How a render runs](#how-a-render-runs)

---

## In Studio

On the takes list, a pair's **Stitch →** opens its stitch page (`/stitch/<take>`). It
loads the take's own alignment (`.align.json`, filling in the shear - see
[calibration.md](calibration.md#per-take-alignment)) or the base calibration, and shows
any frame of the pair warped exactly as the stitcher will warp it:

- **Shift far (top)** / **Shift near (bottom)** - the parallax shear. ←/→ shift both.
- **Rotate** - levels the finished panorama: it rotates the whole panorama and THEN
  applies the crop box, exactly as the preview shows (positive = clockwise; it doesn't
  change how the cameras are aligned).
- **Crop box** - drag it, or its yellow corners; it is the output frame.
- **In ← here** / **Out ← here** - stitch only part of the take (default: all).
- **Seam line** / **overlap blend** - preview aids. The seam is the middle of the
  overlap (the smart seam routes it around moving players); blending and exposure match
  are fixed defaults.
- **Output** - a file name, saved in the takes folder.

**Stitch** starts the job (one at a time; progress on the page and the takes list) and
records every setting in the video's metadata - which is also what gives the video its
**Edit →** button.

---

## Check a take

Studio checks every take: a pair's **Details** on the takes list shows each file's frame
count and any **timing gaps** (missing time in one camera - everything after a gap is out
of step with the other), and the stitch page shows the frame offset between the two
files, read exactly from their capture timestamps. The two files should have
**identical** frame counts, or differ only by that start offset - the recorder stamps a
rigid 30 fps grid, so a capture drop shows up as a duplicated frame, not a shorter file.

**Make a take seekable.** A file that wasn't finalized cleanly has no seek index: it
won't scrub, and stitching falls back to slow frame-grabbing. Remux both halves (fast,
lossless), keeping the `_cam0`/`_cam1` suffixes so pairing still works:

```bash
ffmpeg -fflags +genpts -i take_TS_cam0.mkv -c copy take_TS_cam0_seekable.mkv
ffmpeg -fflags +genpts -i take_TS_cam1.mkv -c copy take_TS_cam1_seekable.mkv
```

---

## The command line

`StitchPipeline` is a plain command-line tool - Studio runs exactly this, and each
stitched video's metadata holds the command that made it. From the repo root:

```bash
studio/native/build/StitchPipeline --source ~/Desktop/takes/take_TS_cam0.mkv \
    --shift-top 4 --shift-bottom 20 --crop 341,119,6141,2134 --out-file stitched.mp4
```

**Every input is a pair** - there is no single-file mode. Pass either file of a pair and
its partner is found next to it (`take_TS_cam0.mkv` / `_cam1`, or `/calib`'s
`cam0_NNN.png` / `cam1_`), or give both as `"left.mkv::right.mkv"`. A take's
`.align.json` is used automatically.

| Flag | Meaning |
|---|---|
| `--source <file>` | input - either file of a pair, or `"a::b"` |
| `--shift-top N` / `--shift-bottom N` | far/near edge alignment (default: the take's `.align.json`) |
| `--shift-x N` / `--shift-y N` | uniform horizontal / vertical shift of cam1 |
| `--pair-offset N\|auto` | frame offset between the files (default `auto`: exact from the capture timestamps on shared-clock takes, brightness estimate on older ones) |
| `--crop x,y,w,h` | output box (full-canvas coords); applied AFTER `--degrees` |
| `--degrees N` | rotate the finished panorama, positive = clockwise |
| `--start N` / `--end N` | frame range (frames: at 30 fps, `frame = seconds × 30`) |
| `--scale F` | render the cylinder at F× radius - same FOV, fewer pixels |
| `--seam N` / `--bands N` / `--no-smart-seam` | seam placement and blending |
| `--no-exposure` | skip matching cam1's brightness to cam0 |
| `--bitrate auto\|90M` | output rate (default `auto`, ~0.20 bpp) |
| `--venc <name>` / `--no-hwenc` | pick or disable the hardware encoder |
| `--calib-dir <dir>` | calibration folder (default: found by walking up) |
| `--out-file <path>` / `--out <dir>` | output |
| `--metadata-file <f>` | store an ffmpeg FFMETADATA file's tags in the output (Studio's settings record) |
| `--no-align` | ignore the take's `.align.json` |

A time range, 1:30 → 3:00:

```bash
studio/native/build/StitchPipeline --source take_TS_cam0.mkv --start 2700 --end 5400 --out-file clip.mp4
```

Confirm no frames were lost - the count should be near `fps × seconds` (or
`end − start + 1`):

```bash
ffprobe -v error -count_frames -select_streams v:0 -show_entries stream=nb_read_frames -of csv=p=0 stitched.mp4
```

---

## How a render runs

One process, as a pipeline: decode → remap + exposure → seam → blend → encode, with
several frames in flight and worker threads taking whichever stage has work. Decode,
seam and encode take frames strictly in order (the smart seam follows the previous
frame's seam), so the seam is one continuous chain over the whole range and the output
is a single file.

The camera files are decoded by ffmpeg with their own colour tags (the cameras record
**full-range BT.709**) and converted exactly. (OpenCV's reader, used until 2026-10-04,
treated them as limited-range BT.601: contrast too high, grass oversaturated and pushed
toward green - panoramas stitched before that date carry that look.)

On an M5 Pro a 5923×1697 crop renders at ~55 fps (just under 2× real time) - the
hardware HEVC encoder's ceiling at that size; the stitching itself is faster. Output is
HEVC in `.mp4`, tagged `hvc1`, bitrate `auto` (~0.20 bpp). `--start` jumps straight to
its frame on an indexed file; otherwise it logs `grab-skipping … (SLOW; remux)`.

**Panorama size** is derived from the calibration, not configured: the cylinder's radius
in pixels equals cam0's focal length, so frame centre is sampled ~1:1 - with this rig's
2104 px focal, about 6800×2370. `--scale` gives fewer pixels at the same field of view;
`--crop` actually crops.

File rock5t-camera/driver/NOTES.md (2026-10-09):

# imx477 driver for Rockchip RK3588 (ROCK 5T) — merge notes

Target: Radxa ROCK 5T, vendor kernel 6.1.84-8-rk2410, built out-of-tree on
the board. `compatible = "sony,imx477"`.

## What came from where

**Rockchip imx577 vendor driver** (`reference/imx577_rockchip_driver.c`) —
the structural base:
- probe/remove flow, mutex/ctrl-handler/subdev/media-pad setup, runtime PM
- power on/off sequence skeleton (power/reset/pwdn GPIOs, regulators
  avdd/dovdd/dvdd, pinctrl `rockchip,camera_default`/`_sleep`)
- i2c read/write helpers and REG_NULL-terminated `struct regval` tables
- v4l2 subdev ops layout, `get_mbus_config`, `get_selection` (incl. the
  4056 -> 4048 CROP_BOUNDS alignment trick), enum_frame_interval with
  `reserved[0] = hdr_mode`
- the full RKMODULE ioctl block + compat_ioctl32: GET_MODULE_INFO,
  GET/SET_HDR_CFG, AWB_CFG, LSC_CFG, SET_QUICK_STREAM, GET_CHANNEL_INFO
- `rockchip,camera-module-*` DT property parsing and the
  `m%02d_%s_imx477 ...` subdev naming rkaiq expects

**Raspberry Pi imx477 driver** (`reference/imx477_rpi_driver.c`) — all
sensor facts:
- chip ID 0x0477 at reg 0x0016
- `mode_common_regs` (one-time init table) and the three mode tables
- exposure (0x0202, offset 22, min 4), analog gain register facts (0x0204,
  code 0..978, gain = 1024/(1024-code) — but see deviation 8: the V4L2
  control contract is the Rockchip linear one), digital gain (0x020e, 8.8
  fixed point)
- VTS via 0x0340 with the long-exposure shift register 0x3100
  (`long_exp_shift`, max 7)
- on-sensor DPC regs 0x0b05/0x0b06 (module param `dpc_enable`, default on)
- XVS trigger register set 0x3f0b / 0x3041 / 0x3040 / 0x4b81 and the
  stop-stream EXTOUT_EN=0 write
- XCLR power-on delay (8ms, datasheet T7)

**NVIDIA/RidgeRun nv_imx477 driver** (`imx477_mode_tbls.h`, fetched from
the L4T public sources mirror
`github.com/Consti10/Linux_for_Tegra .../kernel/nvidia/drivers/media/i2c/`,
RidgeRun copyright 2020 — the same nv_imx477 already validated on the
Jetson Orin) — source for the 3840x2160@30 mode:
- its `imx477_mode_4032x3040_30fps` table: RAW10, 2-lane, line length
  9024, frame length 3102, IOP PLL 24MHz/3*262 = 2096MHz VCO with IOPSYCK
  div 1 -> 2096 Mbps/lane -> **1048 MHz link frequency**; full MIPI
  global-timing register set for that rate (0x080a..0x0819,
  0xe04c..0xe04f)

## Modes (all 2-lane)

| Mode | Format | HTS | VTS def | Max fps | Link freq |
|---|---|---|---|---|---|
| 4056x3040 | SRGGB12 | 24000 | 3500 | 10 | 450 MHz |
| 2028x1520 (2x2 bin) | SRGGB12 | 12740 | 1648 | 40 | 450 MHz |
| 1332x990 (bin+crop) | SRGGB10 | 6664 | 1050 | 120 | 450 MHz |
| 3840x2160 (crop) | SRGGB10 | 9024 | 3102 | 30 | 1048 MHz |

The RPi 2028x1080 50fps crop mode was left out (easy to add later: another
table + mode entry).

### 3840x2160@30 mode provenance (copied vs derived)

Copied verbatim from nv_imx477's validated `imx477_mode_4032x3040_30fps`
(which reads MORE rows/frame than 4K at the same link rate, so the rate is
silicon-proven): all PLL/link registers, line length 9024, frame length
3102, MIPI global timing, readout config, plus the 10-bit support regs
(0x420b..0x9a4d) that nv_imx477 keeps in its common table (prepended to
the mode table here, exactly as the RPi driver does for its 10-bit mode).

Derived (only the window):
- analog crop Y = rows 440..2599 (0x0346/47=0x01b8, 0x034a/4b=0x0a27) —
  cross-validated: the RPi driver's own 2028x1080 mode uses these exact
  values for the same centred 2160-row window
- digital crop X offset 108 = (4056-3840)/2 (0x0409=0x6c), Y offset 0
- crop/output size 3840x2160 (0x040c..0x040f, 0x034c..0x034f)

One `TODO(compile-check)` left in the table: 0x3f56/0x3f57 (per-mode Sony
readout/powersave timing) reused from the 4032x3040 table since the value
for a 2160-row window is unpublished; verify on first stream test.

## Deliberate deviations from the references

1. **PIXEL_RATE = 840 MHz (sensor internal clock), not the Rockchip
   link-based formula.** HTS/VTS are in 840MHz units (RPi
   `line_length_pix`), so `fps = pixel_rate/(hts*vts)` is exact this way.
   The Rockchip formula (`link_freq*2*lanes/bpp` = 150M/180M) would make
   rkaiq's exposure-time math wrong by ~5x. Link frequency (used by the
   CSI2 DPHY) is reported separately and correctly via V4L2_CID_LINK_FREQ.
2. **`rockchip,camera-module-*` DT properties are optional** (imx577 probe
   hard-fails without them). Defaults: index 0, facing "back", module
   "RPI-HQ", lens "default".
3. **xvclk is optional** (`devm_clk_get_optional`): the HQ camera has its
   own on-board 24MHz oscillator. When a clock IS given (fixed-clock or SoC
   output) it is rate-set/enabled the Rockchip way, warning on mismatch.
4. **Trigger mode from DT string** `trigger-mode = "source" | "sink"`
   (absent = free running), applied at stream-on after the mode table,
   before 0x0100=1. Register values per role (validated on Jetson):

   | role | 0x3F0B MC_MODE | 0x3041 MS_SEL | 0x3040 XVS_IO_CTRL | 0x4B81 EXTOUT_EN |
   |---|---|---|---|---|
   | none | 0 | 1 | 0 | 0 |
   | source | 1 | 1 | 1 | 1 |
   | sink | 1 | 0 | 0 | 0 |

   Module param `genlock` (bool, default 1) is the one sync switch for all
   sensors: 1 = each takes its DT role (cam0 source, cam1 sink), 0 = all
   free-run. Runtime: stop streams, write
   `/sys/module/imx477/parameters/genlock`, restart. Boot default:
   `imx477.genlock=0` on the kernel cmdline. Each sensor node gets exactly
   one role — no both-roles path.
5. **Common regs written once per power-on** (RPi's `common_regs_written`
   flag, cleared in power_off) instead of unconditionally in `s_power` —
   works both through the rkaiq pipeline (s_power then s_stream) and plain
   v4l2 (s_stream only). The imx577's HDR/preisp paths were dropped (no HDR
   modes on IMX477); GET/SET_HDR_CFG still answer NO_HDR for rkaiq.
6. **RAW-format regs (0x0112/0x0113/0x0114) prepended to the two 12-bit
   mode tables** — the RPi tables rely on the common table for these, which
   breaks when switching away from the 10-bit 1332x990 mode without a power
   cycle.
7. hflip/vflip and the test-pattern RGB component controls were dropped
   (flips change the Bayer order, which the rkaiq IQ matching doesn't
   handle); Bayer order is fixed SRGGB.
8. **Analog gain follows the Rockchip vendor contract, not the RPi one**:
   V4L2_CID_ANALOGUE_GAIN takes linear gain in 1/16 units (range 16..356,
   step 1, default 32 = 2.0x) and the driver converts internally with the
   imx577 reference's exact formula `reg = 1024 - 1024 * 16 / ctrl_val`
   (integer division), clamped to the IMX477 register ceiling 978
   (~22.26x; ctrl 356 -> reg 978). This is what rkaiq's AE and the
   translated IQ file's sensor_calib gain model assume (the IQ
   TRANSLATION_NOTES flag it as checklist item #1). Unlike the imx577,
   gains above the analog ceiling do NOT spill into digital gain here —
   digital gain stays a separate V4L2_CID_DIGITAL_GAIN control (0x020e,
   8.8 fixed point, RPi convention).

## TODO(compile-check) / risks

No `/* TODO(compile-check) */` markers were left in the code; the genuinely
uncertain spots are listed here instead:
- `RKMODULE_GET_CHANNEL_INFO` / `struct rkmodule_channel_info` and
  `RKMODULE_SET_QUICK_STREAM` must exist in this kernel's
  `linux/rk-camera-module.h` (they do in rk356x/rk3588 6.1 vendor trees; if
  the build errors, delete those two ioctl cases).
- probe signature is the old two-argument `(client, id)` style, matching
  the imx577 reference on this vendor 6.1 tree. If the tree has the
  probe_new conversion applied to i2c, switch to `.probe_new`/one-arg.
- `v4l2_subdev_get_try_format` naming matches the vendor 6.1 reference; a
  newer media stack would want `v4l2_subdev_state_get_format`.
- `vblank_max` uses the RPi long-exposure headroom
  `(128 * 0xffdc) - height`; if rkaiq misbehaves with such a large range,
  clamp to `0xffdc - height`.
- CROP_BOUNDS for the 2028/1332 modes returns the full mode size (imx577
  behaviour); if rkisp complains about 16-pixel alignment on 2028-wide
  modes, mirror the 4048 trick there (3840 and 2160 are already aligned).
- **4K mode link rate**: 2096 Mbps/lane is above D-PHY v1.2 (1.5G) but
  within both the IMX477 (2.1G/lane max) and the RK3588 D-PHY RX (2.5G)
  limits. Risks for first stream test: the RK3588 CSI2/DPHY driver must
  pick up the 1048MHz entry from V4L2_CID_LINK_FREQ (the driver switches
  the control per-mode in set_fmt, imx577-style); flex/cable signal
  integrity at 2.1G-class rates; and nv_imx477's odd 0x0820/0x0821 value
  (0x20c0 = 8384 "Mbps" vs the expected 4192 total) was copied verbatim
  since it streamed fine on Jetson.

## Build / install on the ROCK 5T (OBSOLETE)

> **Don't use this.** It loads the driver as a module, which can never work on
> this board's kernel (the camera pipeline drops any sensor that isn't built in -
> see `../kernel-build/README.md`). The driver is built INTO the camera kernel,
> which `rock5t-camera/setup.sh` installs. Kept for history.

```sh
sudo apt install linux-headers-$(uname -r)   # if not present
cd <repo>/rock5t-camera/driver      # after pulling the repo
make
sudo make install                            # copies to /lib/modules/.../extra + depmod
sudo modprobe imx477                         # or: sudo insmod ./imx477.ko
dmesg | grep imx477                          # expect "Detected Sony imx0477 sensor"
```

DT sensor node sketch (per camera, on its i2c bus, addr 0x1a):

```dts
imx477: imx477@1a {
	compatible = "sony,imx477";
	reg = <0x1a>;
	/* clocks optional - module has on-board 24MHz osc */
	avdd-supply = <&vcc_cam_avdd>;   /* or fixed dummies */
	dovdd-supply = <&vcc_cam_dovdd>;
	dvdd-supply = <&vcc_cam_dvdd>;
	reset-gpios = <&gpio... GPIO_ACTIVE_HIGH>;  /* XCLR */
	rockchip,camera-module-index = <0>;
	rockchip,camera-module-facing = "back";
	rockchip,camera-module-name = "RPI-HQ";
	rockchip,camera-module-lens-name = "default";
	trigger-mode = "source";        /* other sensor: "sink" */
	port {
		imx477_out: endpoint {
			remote-endpoint = <&mipi_in_cam0>;
			data-lanes = <1 2>;
		};
	};
};
```

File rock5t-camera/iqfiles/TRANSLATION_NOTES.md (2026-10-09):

# imx477_RPI-HQ_default.json — translation notes

**Status: IN USE — loaded, A/B tested and tuned on hardware.**
Round 1 (NR/sharpening) and the AE setpoint raise were validated outdoors on
2026-09-13; see the bring-up logs in `../ROCK5T_CAMERA.md`. The
section-by-section notes below describe the ORIGINAL translation from the
reference files — later tuning is recorded in those logs and in
`gen_imx477_iq.py`, which remains the source of truth: edit the script and
regenerate, never hand-edit the JSON.

Target: RK3588 (Rock 5T), rkisp v30 schema, rkaiq 6.8.0.
Filename follows Radxa's `<sensor>_<module>_<lens>.json` convention: sensor `imx477`,
module `RPI-HQ`, lens `default`.

## Sources

| File | Role |
|---|---|
| `reference/imx577_radxa_12m_iq.json` | **Primary skeleton.** Radxa's shipping RK3588 IQ for the Sony IMX577 — the IMX477's near-identical sibling (same 12.3MP class, 1.55µm pixel, same Sony CFA family, same hyperbolic gain law). Everything not listed below is KEPT from it verbatim. |
| `reference/imx477_rpi_tuning.json` | Raspberry Pi's published lab calibration for the IMX477 (libcamera format). Source of all measured numbers that were overridden. |
| `reference/imx415_radxa_iq_skeleton.json` | Secondary structural reference only (used to confirm schema conventions, e.g. the gamma X-grid; no numbers taken from it). |
| `reference/imx577_rockchip_driver.c` | Confirms the gain contract (see sensor_calib). |

The skeleton was switched from the imx415 file to the imx577 file mid-work: the
imx577 module shares the IMX477's pixel and gain architecture, so its noise/NR,
BLC and sensor sections are already approximately right and could be **kept**
instead of translated. Two cross-checks validated the switch:

- **BLC cross-validation:** the imx577 file's measured black level is 254.7–257
  (12-bit); RPi's imx477 value is 4096 on a 16-bit scale = exactly **256** at
  12-bit. Independent calibrations agreeing to ~1 LSB.
- **Gain law:** `imx577_rockchip_driver.c` line ~2054 converts V4L2 linear gain to
  `gain_reg = 1024 − 1024/gain` — the identical formula the IMX477 datasheet/RPi
  driver uses.

Generator script (reproducible): the JSON was produced by
`rock5t-camera/iqfiles/gen_imx477_iq.py` (run it from anywhere; paths are
absolute-from-repo). Every transform below matches its printed output — edit
the script and regenerate rather than hand-editing the JSON.

---

## Section-by-section

### sensor_calib — mostly KEPT, 2 edits
- `resolution`: 4048x3040 → **4056x3040** (IMX477 full active array, as the RPi
  kernel driver reports). *If the ported Rockchip imx477 driver crops to a
  different mode (e.g. 4048 like the imx577 one), change this to match — and add
  a matching `lsc_v2` resolution entry.*
- `CISTimeSet.Linear.CISTimeRegMin`: 1 → **4** (RPi imx477 kernel driver:
  minimum coarse integration = 4 lines).
- `Gain2Reg` KEPT: `EXPGAIN_MODE_LINEAR`, `GainRange [1, 16, 32, 0, 1, 32, 512]`
  (linear gain, 1–16x, encoded ×32). The Rockchip imx577 driver takes linear
  V4L2 gain and does the Sony hyperbolic register conversion internally
  (`1024 − 1024·16/val`, with driver-side dgain handover above ~22x). A ported
  imx477 driver must keep the same contract; then this section is correct as-is.
  **This is the #1 thing to verify once a driver exists** — a mismatch shows up
  as AE oscillation / brightness steps when gain changes.
- `CISLinTimeRegMaxFac [1, 22]` KEPT — matches IMX477 too (max exposure =
  VTS − 22 lines in the RPi driver).

### module_calib — KEPT
`FNumber 1.6 / EFL 5.2` are the Radxa 12M module's optics, not ours (CS-mount
lens on the HQ camera, lens TBD). Only used for the (disabled) EnvLv calibration
and metadata; update when the rig's lens is chosen.

### ablc_calib (black level) — KEPT
Skeleton values ~254.7–257 per channel per ISO (12-bit domain).
Scale inference: RPi gives 4096 on 16-bit → 4096/16 = **256 at 12-bit**; the
skeleton's magnitudes (~256, vs Sony 12-bit pedestal class) confirm the section
is in 12-bit units. Since Radxa's measured imx577 values equal RPi's imx477
value to ≈1 LSB, the measured (slightly per-ISO-varying) values were kept rather
than flattened to a constant 256.

### wb_v21 (AWB) — gains replaced, detection geometry KEPT
Computed from RPi `rpi.awb.ct_curve` — entries `(CT, r, b)` with `r = R/G`,
`b = B/G` of grey under that illuminant; gain = 1/r, 1/b; linear interpolation
in CT (same as libcamera):

| Illuminant | CT used | r, b (interp) | Rgain | Bgain |
|---|---|---|---|---|
| HZ  | 2350 | 0.6009, 0.3093 | 1.66417 | 3.23311 |
| A | 2856 | 0.5047, 0.4057 | 1.98143 | 2.46486 |
| TL84| 4000 | 0.3983, 0.6036 | 2.51090 | 1.65668 |
| CWF | 4150 | 0.3880, 0.6210 | 2.57763 | 1.61037 |
| D50 | 5000 | 0.3417, 0.6874 | 2.92631 | 1.45476 |
| D65 | 6500 | 0.3085, 0.7169 | 3.24144 | 1.39496 |
| D75 | 7500 | 0.2981, 0.7352 | 3.35477 | 1.36021 |

Applied to:
- `lightSources[*].standardGainValue` (the skeleton has 5 sources: A, CWF, D65,
  HZ, TL84 — no D50/D75 entries exist in this AWB section).
- `lightSources[*].defaultDayGainLow` = D50 gains, `defaultDayGainHigh` = D65
  gains (skeleton convention: low-LV / high-LV daylight fallback).
- `manualPara.cfg.mwbGain` = D50 gains (its scene tag is DAYLIGHT/CCT 5000).

**KEPT (not translatable without hardware):** all white-point *detection*
geometry — `uvRegion`, `xyRegion`, `rtYuvRegion`, `rgb2TcsPara`,
`rgb2RotationYuvMat`, weights. These are measured in rkisp statistics space for
the imx577 module.

**Known consequence (deliberate):** I partially reverse-engineered the xy space
(x ≈ `−0.618·log2(r) + 0.786·log2(b) + 1.440` reproduces the skeleton's region
x-ranges for its own illuminants). Under that transform the IMX477's daylight
white point lands at x ≈ 2.11 — *outside* every skeleton region (max ≈ 1.92).
So outdoors the AWB will likely classify no illuminant and fall back to
`defaultDayGainLow/High`, which are set to the correct measured IMX477 D50/D65
gains. For an outdoor-only draft this is an acceptable, predictable behavior;
proper region recalibration needs the RKISP tuning tool with the real camera.
The y-axis formula could not be recovered, which is why regions were not
shifted numerically.

Note the large gain difference vs the skeleton (imx577 D65 R≈1.94 vs imx477
D65 R≈3.24): plausibly the Radxa module's IR-cut filter; RPi's numbers are for
exactly our sensor + HQ-camera IR filter stack, so they were preferred.
`sensitivity_r = sensitivity_b = 1.05` from the RPi file was **not** applied
(module-to-module trim; ±5% uncertainty on all gains above).

### ccm_calib — matrices + awbGain replaced, structure KEPT
- `aCcmCof[*].awbGain` (7 illuminants, incl. D50/D75) → the RPi-derived
  [Rgain, Bgain] pairs above. These drive CCM illuminant selection by distance
  from the applied WB gain, so they must match the AWB numbers.
- `matrixAll[*].ccMatrix`: RPi `rpi.ccm` matrices (cts 2850/2960/3580/4559/
  5881/7600), **linearly interpolated in CT** to each skeleton illuminant CT
  (HZ clamped to the 2850 matrix). Convention check: RPi rows sum to 1.0,
  identical to the skeleton's row convention → **no re-normalization or
  reordering needed** (rows re-normalized to sum exactly 1 after interpolation
  anyway; offsets 0).
- Saturation-74 variants: RPi has no desaturated set, so
  `M_74 = 0.74·M + 0.26·L` where every row of `L` is the luma vector
  `rgb2y_para/128 = [0.2969, 0.5859, 0.1172]` (standard "blend toward luma"
  desaturation; rows still sum to 1). **Approximation** — but this skeleton's
  `gain_sat_curve` pins saturation at 100 for all gains, so the _74 matrices are
  structural only and never selected at runtime.
- `lumaCCM`, `illu_estim`, tolerances: KEPT.

### agamma_calib_v11 — replaced with RPi tone curve
- Skeleton X grid recovered and verified: the 49 `Gamma_curve` samples sit on
  the fixed rkisp grid `[0,1,2,…,8,10,12,…,4095]` (dyadic segments); the
  skeleton's own values reproduce `x^(1/2.2)` on that grid to ±0.5 LSB, which
  confirms both the grid and the 12-bit domain.
- Conversion: for each grid X, input16 = X·65535/4095 → piecewise-linear lookup
  of RPi `rpi.contrast.gamma_curve` (16-bit in/out pairs) → output·4095/65535,
  rounded; endpoint forced to 4095; monotonicity asserted.
- **Character note:** RPi's curve is piecewise-linear starting (0,0)→(1024,5040)
  (16-bit), so deep shadows are lifted far less than the skeleton's pure 2.2
  curve (first sample 5 vs 93), while mids are slightly brighter (25% grey →
  2540 vs 2181/4095). That is genuinely the RPi HQ rendering; if shadows look
  crushed on hardware, this section is the knob.

### lut3d_calib — KEPT (disabled)
Already `enable: 0` in the skeleton. Left off: the RPi pipeline has no 3D LUT,
its CCM is the entire color mapping.

### lsc_v2 (lens shading) — neutralized (deliberate)
- RPi `rpi.alsc` tables were **not transplanted** (they correct the RPi stock
  lens, not the rig's CS-mount lens); the skeleton's tables correct the Radxa
  12M module lens — also wrong. All 33 skeleton tables (17×17 grid, all four
  channels) set to **1024 = 1.0x** (unity; skeleton's own minimum coefficient
  is 1024, confirming the fixed-point scale).
- LSC left `enable: 1` with unity tables — guaranteed no-op, structurally
  identical to a shipping file.
- Added resolutions `4056x3040` (full frame) and `2028x1520` (2×2 binned) with
  unity tables cloned per illuminant (sector sizes: even values summing to the
  frame — 12×254+4×252 / 16×190, and 6×128+10×126 / 8×96+8×94), placed first in
  `resolutionAll`. Original 4048x3040 / 3840x2160 / 1920x1080 entries kept.
  Table count 33 → 55.
- `alscCoef.illAll[*].wbGain` updated to the RPi-derived gains (GRAY kept [1,1])
  so illuminant selection stays consistent, even though all tables are unity.
- Real LSC for the actual lens must be calibrated on hardware (flat-field, per
  CT); until then expect corner falloff and possible slight color vignetting.

### ae_calib — KEPT
Route caps at 64x total gain via the driver's combined-gain handling (the
imx577 driver folds >22x into sensor dgain transparently; a ported imx477
driver should do the same). Time route tops at 30ms (30fps). Setpoints,
antiflicker (50Hz — change to 60Hz for US venues if relevant), damping: all
Radxa's. RPi AGC content (metering weights, y_targets) was **not** ported —
different algorithm structure, unclear mapping.

### Noise reduction (bayer2dnr_v2, bayertnr_v2, ynr_v3, cnr_v2, sharp_v4, gain_v2) — KEPT
Calibrated for the imx577's identical 1.55µm pixel — the best available match.
RPi's noise model (`rpi.noise`: stddev ≈ 2.767·√level, 16-bit domain) does not
map cleanly onto rkaiq's per-ISO, per-frequency sigma tables, so no scaling was
attempted. Keep the RPi constants on file as ground truth for later hardware
tuning.

### Everything else — KEPT verbatim
`adegamma` (off), `agic`, `debayer`, `amerge`, `adrc`, `adehaze`, `adpcc`
(defect pixels — imx577-measured but same pixel class), `aldch` (off), `cpsl`,
`cproc`, `ie`, `colorAsGrey`, `cac_v03/v10`, `af_v30` (the rig has a manual CS
lens — AF config is inert without a VCM; disable later if it logs errors),
`afec` (off), `csm`, `cgc`, top-level `uapi`, `sys_static_cfg`, scene markers
(`main_scene[0] "normal"` / `sub_scene[0] "day"`).

Output serialized in the same cJSON style as the shipping file (tab indent,
inline scalar arrays); validated with `python3 -m json.tool` and byte-equal
round-trip reparse.

---

## Hardware validation checklist (first light, in order)

1. **File loads:** rkaiq starts without parse/calib errors with the file in
   `/etc/iqfiles/` (name must match what the driver's module info reports —
   sensor `imx477`, module `RPI-HQ`, lens `default`). If rkaiq rejects it,
   compare against `imx577_radxa_12m_iq.json` loading on the same board first.
2. **Exposure/gain sanity (top risk):** point at a static scene, watch AE
   settle. Oscillation, stair-stepping, or brightness jumps when gain crosses
   values ⇒ the driver's gain contract doesn't match `Gain2Reg` (see
   sensor_calib note). Verify the ported imx477 driver interprets
   V4L2 analogue gain as linear ×16 units and applies `1024−1024/g` itself.
3. **Black level:** cap the lens; histogram of a raw-ish dark capture should
   sit at ~0 after ISP (no purple/green shadows, no crushed floor). Wrong BLC
   shows as milky or tinted shadows. Expected pedestal 256@12bit.
4. **Grey neutrality outdoors (the priority):** grey card / concrete / white
   lines in full sun and in shade. Expect the AWB to run on the daylight
   fallback gains (see wb_v21 note) — verify WB gains reported by rkaiq land
   near R≈2.9–3.3, B≈1.36–1.46. A strong cast means the fallback isn't being
   hit as predicted; check rkaiq AWB logs for which light source it claims.
5. **Skin / grass / sky sanity:** grass should be green not teal (CCM row 2),
   sky blue not cyan (row 3), skin not orange (row 1 + CT interp). If daylight
   color is off but grey is neutral, suspect the CCM CT-interpolation choices
   or the AWB→CCM `awbGain` matching.
6. **Shadow rendering:** if shadows look crushed vs the Pi's output, revisit
   the gamma section (RPi curve has a gentle toe).
7. **Lens shading:** expect visible corner falloff (LSC is unity). Calibrate
   real LSC tables for the chosen CS lens with the Rockchip tuning tool, per CT.
8. **Resolution match:** confirm the driver's active mode is 4056x3040 (or fix
   `sensor_calib.resolution` + add the LSC resolution entry to match).
9. **Antiflicker:** venue lighting at 60Hz mains ⇒ switch
   `AecAntiFlicker.Frequency` to `AECV2_FLICKER_FREQUENCY_60HZ`.

## Biggest uncertainties (ranked)

1. **Gain2Reg vs the (not yet existing) Rockchip imx477 driver** — AE correctness
   hinges on the driver mirroring the imx577 driver's linear-gain contract.
2. **AWB detection regions are imx577-module measurements** — daylight expected
   to ride the fallback gains; indoor/mixed light will misbehave. Needs real
   calibration.
3. **CCM CT-interpolation** — RPi matrices were measured at 6 CTs and linearly
   interpolated to the skeleton's 7 illuminant CTs; daylight range (4559–7600)
   is well covered, deep warm (HZ 2350) is clamped/extrapolated.
4. **NR tuned for imx577 module** — same pixel, different lens/ISP gains; high
   ISO texture/chroma noise balance unverified.
5. **LSC unity** — cosmetic until calibrated (corner falloff, possible color
   shading with wide CS lenses).

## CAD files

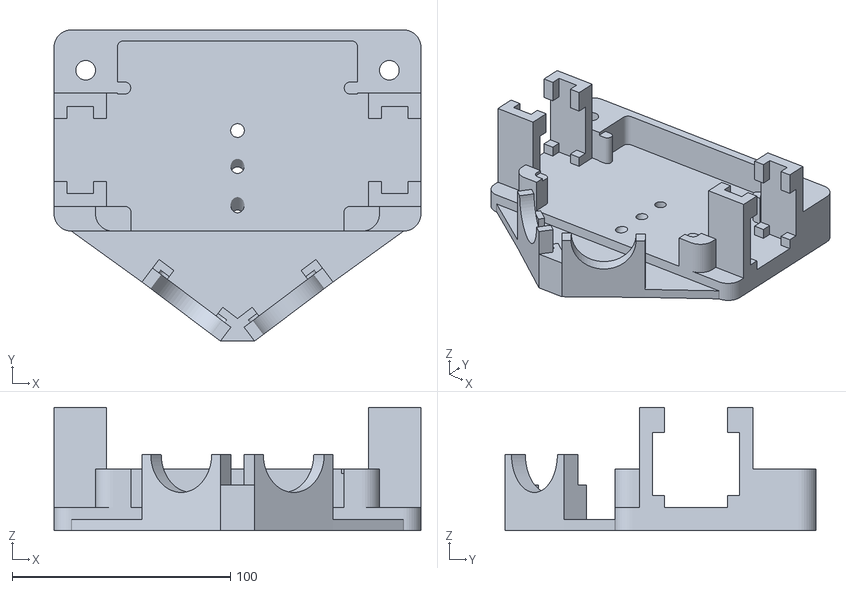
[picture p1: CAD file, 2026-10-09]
hardware/housing/Rock Housing - Bottom - PRINT ORIENTED.stl
168.2 x 142.6 x 56.5

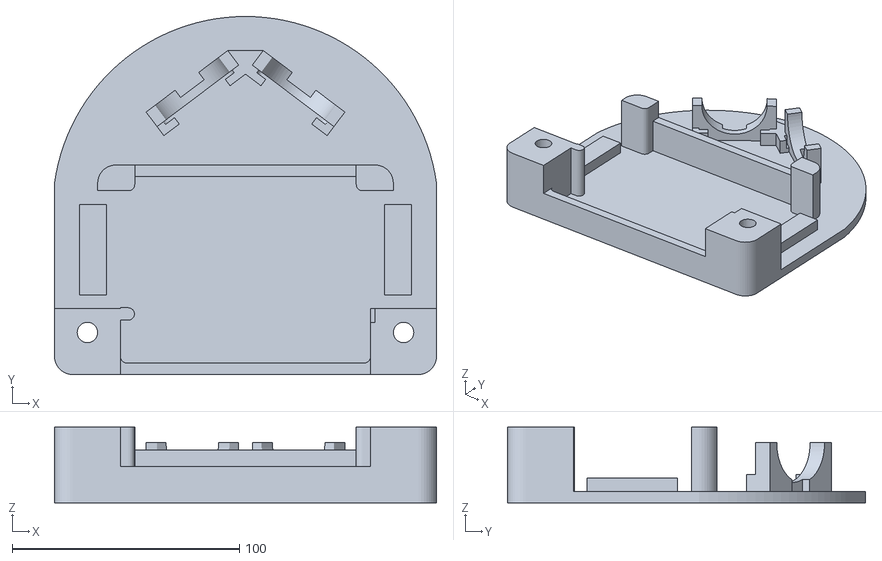
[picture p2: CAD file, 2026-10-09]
hardware/housing/Rock Housing - Top - PRINT ORIENTED.stl
168.2 x 157.6 x 33.3

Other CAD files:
hardware/housing/Rock Housing - Bottom.3mf
hardware/housing/Rock Housing - Top.3mf
hardware/housing/Rock Housing - Bottom.stl
hardware/housing/Rock Housing - Top.stl

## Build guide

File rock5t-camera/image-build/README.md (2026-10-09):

# Ready-to-flash Rock image

Builds one image file that turns a ROCK 5T into the camera rig with nothing to run
on the Rock: flash it, boot it, and the recorder is up at `http://<rock-ip>:8080`.

It is Radxa's stock image — the exact build the rig was developed on — with what
`rock5t-camera/setup.sh` would install already in it:

| In the image | |
|---|---|
| Radxa ROCK 5T Debian 12 KDE, release `rsdk-r7` (2026-07-06) | the base: OS, Radxa's camera software (rkaiq 3A, MPP encoder), boot tools |
| the camera kernel (`kernel-N` release, the one `setup.sh` names) | the IMX477 driver built in; boots by default, Radxa's kernel kept as a fallback; kernel updates held |
| the camera overlay, in `/boot/dtbo/` | both cameras + genlock roles |
| the IQ tuning file, in `/etc/iqfiles/` | |
| the 3A service fix (`../system/rkaiq_3A-override.conf`) | |
| ffmpeg, exfatprogs and the other packages `setup.sh` installs | |
| a git checkout of this repo, ending up in `/home/radxa/<repo>` | so the Rock can `git pull` |
| the recorder service, enabled | starts at every boot |
| `camera-network.txt` on the `config` partition + the service that applies it | Wi-Fi and hotspot (default `VeeryCam` / `changeme123`), filled in before the first boot, read once |
| the hostname, if built with `RIG_HOSTNAME=` | |

What Radxa's own first boot does is unchanged: it creates the `radxa` user (password
`radxa`; change it), generates the Rock's own SSH keys, grows the root partition to fill
the card, and enables SSH when no screen is connected. One extra first-boot step
(`firstboot/`) then moves the repo checkout into `/home/radxa` and hands it over, and
the recorder starts after it. `/etc/camera-rig-image` records what an image was built
from.

## Build

Needs Docker (running) and ~20 GB free. From the repo root, with everything committed
(the image carries a checkout of the current commit):

```bash
RIG_HOSTNAME=veery rock5t-camera/image-build/build-image.sh 1
```

The number is the image revision. The first run downloads Radxa's image (1.4 GB,
checked against Radxa's checksum) and the kernel into `work/` — both from this repo's
own releases (`radxa-rsdk-r7`, an unmodified mirror of Radxa's file; `kernel-N`), so
the build needs nothing outside this repo. Later builds reuse them. The result is `out/rock5t-camera-image-1.img.xz` (~1.5 GB) plus a
`.sha256`. `work/` and `out/` are not committed. `ALLOW_DIRTY=1` builds from
uncommitted changes, for testing only.

The build fails rather than produce an image whose boot menu doesn't start the camera
kernel with the overlay.

## Publish

```bash
gh release create image-1 rock5t-camera/image-build/out/rock5t-camera-image-1.img.xz \
    rock5t-camera/image-build/out/rock5t-camera-image-1.img.xz.sha256 \
    --title "Rock image 1" --notes "what changed"
```

GitHub allows 2 GB per file; the image is ~1.5 GB.

Keep the `kernel-N` release the image was built from (the build downloads it, and
`setup.sh` uses it to update a Rock that is already running) and the `radxa-rsdk-r7`
release (the base every image is built on).

## When to build a new image

After changing anything the image carries — the kernel (bump `KREL`/`KREV` in
`rock5t-camera/setup.sh` first), the overlay, the tuning file, the 3A fix, the
recorder. A Rock that is already running doesn't need reflashing: `git pull` and
`rock5t-camera/setup.sh` bring it up to date.

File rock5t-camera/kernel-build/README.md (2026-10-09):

# Kernel build: IMX477 built in (`CONFIG_VIDEO_IMX477=y`)

The Radxa/Rockchip vendor kernel assumes camera sensor drivers are built
into the kernel: the builtin pipeline (csi2-dphy → mipi-csi2 → rkcif →
rkisp) purges any sensor that hasn't async-registered by the end of kernel
init (`late_initcall`, i.e. before `/init` runs) — permanently. A loadable
`imx477.ko` therefore can never join the media graph on a stock kernel, no
matter how it's ordered (softdep, modules-load.d, initramfs: all tried,
all lose by design; full autopsy in `../ROCK5T_CAMERA.md`, bring-up log
2026-09-11 — a partial runtime-overlay workaround lives in git history at
df6b0ec). Building the driver in — exactly like every in-tree Rockchip
sensor — makes the problem not exist.

## What defines the kernel (all in this repo)

| Piece | Where |
|---|---|
| Radxa kernel source, pinned to one commit | `KERNEL_COMMIT` in `build-kernel-docker.sh` (`34337a9c76fd`, branch `linux-6.1-stan-rkr4.1`, 6.1.84) |
| The IMX477 driver | `../driver/imx477.c`, added by `inject-driver.sh` |
| Kernel settings | `kernel.config` — the Rock's own config + `CONFIG_VIDEO_IMX477=y` + release suffix `-8-rk2410-imx477` |

Built kernels are published as **GitHub Releases** (`kernel-N`, with the two
`.deb` files attached), not committed - so nobody has to rebuild to install.

## Install a released kernel (no build)

`rock5t-camera/setup.sh` does this for you (and the rest of the Rock's setup) - it
installs the release named by `KREL`/`KREV` at its top. To do it by hand: on the Mac, download the two `.deb` files from the repo's Releases page
(e.g. `kernel-1`), or with the GitHub CLI:

```
gh release download kernel-1 --repo JWylie43/veery-field-camera --dir ~/Desktop/kernel-1
scp ~/Desktop/kernel-1/*.deb radxa@<rock-ip>:~/
```

Then on the Rock:

```
sudo dpkg -i ~/linux-image-*-imx477-1_arm64.deb ~/linux-headers-*-imx477-1_arm64.deb
sudo u-boot-update && sudo reboot
```

Check with `uname -v` (build number) and `cat /sys/module/imx477/parameters/genlock` (`Y`).

## Build on any machine (Docker) - recommended

Mac (Apple Silicon or Intel) or Linux (arm64 or x86-64). Nothing to install but
Docker:

```
cd rock5t-camera/kernel-build
REV=2 ./build-kernel-docker.sh        # the next kernel's number: released as kernel-2
```

The packages land in `kernel-build/out/` (ignored by git). The first build
takes ~30-60 min (the whole kernel and its modules); the source and objects
are kept in the Docker volume `imx477-kernel-src`, so a rebuild after a
driver change takes minutes. On arm64 hosts it builds natively; on x86-64 it
cross-compiles. `docker volume rm imx477-kernel-src` frees the space (~15 GB).

## Build + install on the Rock (~1–2 h)

```
cd <repo>/rock5t-camera/kernel-build
./build-kernel.sh              # clone radxa/kernel, inject driver, build debs
./build-kernel.sh install      # dpkg -i + u-boot-update
sudo reboot
```

This one takes its settings from the running kernel instead of
`kernel.config`, so run it from the stock kernel, or prefer the Docker build.

The new kernel installs alongside the stock one (release string suffix
`-imx477`); the stock kernel remains in the u-boot menu as a fallback.
No reflash. Use the normal full-enable boot overlay
(`../overlay/rock-5t-dual-rpi-hq-imx477.dts`) — rebuild it and the boot
dtbo installs unchanged.

## Publishing a new kernel release

After building and testing a new revision N on the Rock (then bump `KREV` - and
`KREL` if the version string changed - at the top of `rock5t-camera/setup.sh`):

```
gh release create kernel-N rock5t-camera/kernel-build/out/linux-image-*-imx477-N_arm64.deb \
    rock5t-camera/kernel-build/out/linux-headers-*-imx477-N_arm64.deb \
    --title "Kernel N" --notes "what changed in the driver"
```

(or on github.com: Releases → Draft a new release → tag `kernel-N` → attach
the two `.deb` files → Publish).

## Radxa kernel updates

A Radxa kernel update does NOT carry our driver: either hold the kernel
(`sudo apt-mark hold 'linux-image*' 'linux-headers*'`) or re-run this
script against the new source (`rm -rf ~/radxa-kernel`, adjust `BRANCH`
if Radxa moved on, run both steps again).

## Known-broken vendor bits (independent of kernel choice)

- `rkaiq_3A.service` kills its own daemon at start (oneshot wrapper +
  `ExecStop=killall` — the wrapper backgrounds the server, systemd sees it
  exit and runs stop). **Fixed on the Rock 2026-09-11** with a drop-in at
  `/etc/systemd/system/rkaiq_3A.service.d/override.conf`:

  ```
  [Service]
  Type=simple
  ExecStart=
  ExecStart=/usr/bin/rkaiq_3A_server
  ExecStop=
  ```

  (plus `chmod 644` on the world-writable unit). Any fresh install needs
  this drop-in too - it is `../system/rkaiq_3A-override.conf`, installed by
  `rock5t-camera/setup.sh`.

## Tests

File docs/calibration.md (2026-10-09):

# Calibration and alignment

How the rig's camera geometry is measured: the base calibration (once per housing) and
the per-take alignment (every take). Quick start is in the [README](../README.md).

- [Two facts](#two-facts)
- [Base calibration](#base-calibration)
- [Per-take alignment](#per-take-alignment)

---

## Two facts

**The calibration is fisheye, always.** The CIL391 lenses are 110° with -16% barrel. A
pinhole+polynomial fit leaves a uniform ~2.6 px residual - a model mismatch, not noise;
the equidistant model lands at ~0.23 px. `calibrate.py` writes `"model": "fisheye"` and
the stitcher **rejects** anything else, because the wrong projection doesn't fail
loudly - it silently yields a plausible-looking panorama built from the wrong geometry.

**Orientation.** The cameras are mounted upside down. Everything that saves or shows an
image (recording encoder, panel previews, `/calib` snapshots) rotates it 180°, so files
on disk are upright, and calibration is solved in that orientation (the current JSONs
are). The stitcher then sees cam1 to the left of cam0 and swaps the two automatically.

---

## Base calibration

`calibration/cam0_intrinsics.json`, `cam1_intrinsics.json` and `stereo_extrinsics.json`
- the stitcher finds them there. Do this once per housing build, and again if the mount
is disturbed. Intrinsics are mount-independent; **extrinsics are not**.

### Capture (on the Rock)

Show `calibration/charuco_board.png` full-screen (a TV works) and open the recorder
panel's **Calibration Snapshots** page, `http://veery.local:8080/calib`. Each **Take
Snapshot** saves a full-res 3840×2160 pair, `cam0_NNN.png` + `cam1_NNN.png`, into
`~/calib-pairs` on the Rock.

- For **intrinsics**, walk the board around each camera's whole frame, edges and
  corners included (a shot only one camera sees still counts for that one).
- For **extrinsics**, hold the board still where *both* cameras see it - the pairs are
  simultaneous, which is what the stereo solve needs.

Aim for ~30-40 poses at varied depth and tilt.

### Solve (on the Mac)

```bash
cd calibration
scp -r radxa@veery.local:~/calib-pairs images-pairs
../.venv/bin/python calibrate.py --cam0-glob 'images-pairs/cam0_*.png' --cam1-glob 'images-pairs/cam1_*.png' \
        --square-mm <measured> --marker-mm <measured>
```

Results are written next to the script, which is where the stitcher looks. The model is
fisheye, always - there is no `--model` flag. `--square-mm`/`--marker-mm` are the board
**as displayed**: measure a square on the screen every session (it changes with the
viewer's zoom; 71/53 mm was the TV in full-screen Preview on 2026-10-03). Wrong values
scale the baseline wrongly.

To re-solve only the extrinsics against already-good intrinsics:

```bash
../.venv/bin/python calibrate.py --use-intrinsics . --square-mm 71 --marker-mm 53 \
        --cam0-glob 'images-pairs/cam0_*.png' --cam1-glob 'images-pairs/cam1_*.png'
```

**Good output:** RMS well under 1 px (this rig's intrinsics solve at ~0.23 px) and
~104.5° horizontal FOV. Eyeball the sanity images it writes: straight lines straight in
`camN_undistort_sample.jpg`; in `stereo_reprojection_sample.jpg` the red crosses
(solved) inside the green circles (detected) in BOTH halves. Then stitch one pair and
look at the seam - the real test (from the repo root):
`studio/native/build/StitchPipeline --source calibration/images-pairs/cam0_013.png --out-file pano.jpg`.

**`calibrate.py` refuses to write `stereo_extrinsics.json` above 3 px RMS**, because a
bad extrinsic still produces a plausible-looking panorama. The usual cause is pairing
frames that weren't taken together (two separate per-camera shoots sort into unrelated
"pairs") - use `/calib` pairs. `--force-extrinsics` overrides. The stereo solve maps
corners through each camera's fisheye model before `cv2.stereoCalibrate`, which only
knows the pinhole model (fed fisheye coefficients directly it gave 28 px RMS and a
2.8° "toe-in" on good pairs).

### The current calibration

First housed solve (2026-10-03, 26 pairs): yaw 74.7°, 1.5° residual tilt, baseline
67.8 mm, 1.87 px RMS (an upper bound - each board pose comes from cam0 alone and is
carried into cam1); the seam through the board is continuous.

**Scene refinement (same day).** On real footage that solve left cam1 ~12 px low at the
seam and tipped (~23 px per 1000 px across the overlap) - a ~0.3° tilt and ~1.2° roll
error. With the board only ~1 m away and seen at the fisheye edges, a small tilt and a
small vertical offset look alike, so the solver traded one for the other. The rotation
was corrected from footage using only **parallax-free** measurements:

| Correction | Measured from |
|---|---|
| pitch −0.29° | vertical offset at the seam column |
| roll +1.24° | change of vertical offset across the overlap, after fitting out the parallax part (which grows toward the near rows) |
| yaw −0.40° | horizontal offset on the far field just below the horizon |

After it the cameras agree for a scene at infinity (vertical ~0.3 px, far-field
horizontal ~0), and the shear (`--shift-top`/`--shift-bottom`) carries only parallax.
The corrections and the original matrix are under `scene_refinement` in the JSON;
`translation_mm` is still the board value (the stitcher ignores it).

---

## Per-take alignment

The mount can settle by a fraction of a degree between sessions (2026-10-08: −11 px
vertical at the seam after a week in the same housing), which shear can't fix. So each
take gets its own alignment, measured on its own footage: in Studio, tick the takes and
**Align selected**. By hand, from the repo root:

```bash
.venv/bin/python studio/refine_extrinsics.py --align ~/Desktop/takes/take_TS_cam0.mkv
```

(~10 s; either file of the pair works; the files are paired by their capture timestamps,
as the stitcher pairs them.) It solves that take's tilt / roll / yaw correction from
parallax-free measurements only, measures its shear, and writes both to
`take_TS.align.json` next to the take. The stitcher and Studio then use it for that take:
its rotation replaces the base rotation, and its shear fills in Shift far / Shift near
(CLI: unless you pass `--shift-top`/`--shift-bottom`/`--shift-x`; `--no-align` ignores
the file). Takes without one use the base calibration, which `--align` never changes.

- `--check` measures and reports only (against the take's file if it has one; `--base`
  for the base calibration).
- `--apply` writes the correction into the BASE calibration instead (with a
  `.bak-<time>` backup) - only for when the rig has settled for good.

Needs a daytime take with textured ground in the overlap. The rotation is parallax-free;
the shear is the measured parallax for that rig position (the straight-line best fit for
the ground - nearer people and objects are left to the smart seam).

**Why shear at all:** the calibration aligns the cameras' *directions*, which is exact
only for distant things. The lenses are ~68 mm apart, so a nearer object lands at a
different spot in each view - roughly 2104 px × 0.068 m / distance: ~3 px at 50 m,
~15 px at 10 m, ~30 px at 5 m. The far edge of the field needs ~nothing; the near edge
(bottom of frame) a few to a few tens of px, depending on how close the rig is to the
touchline.

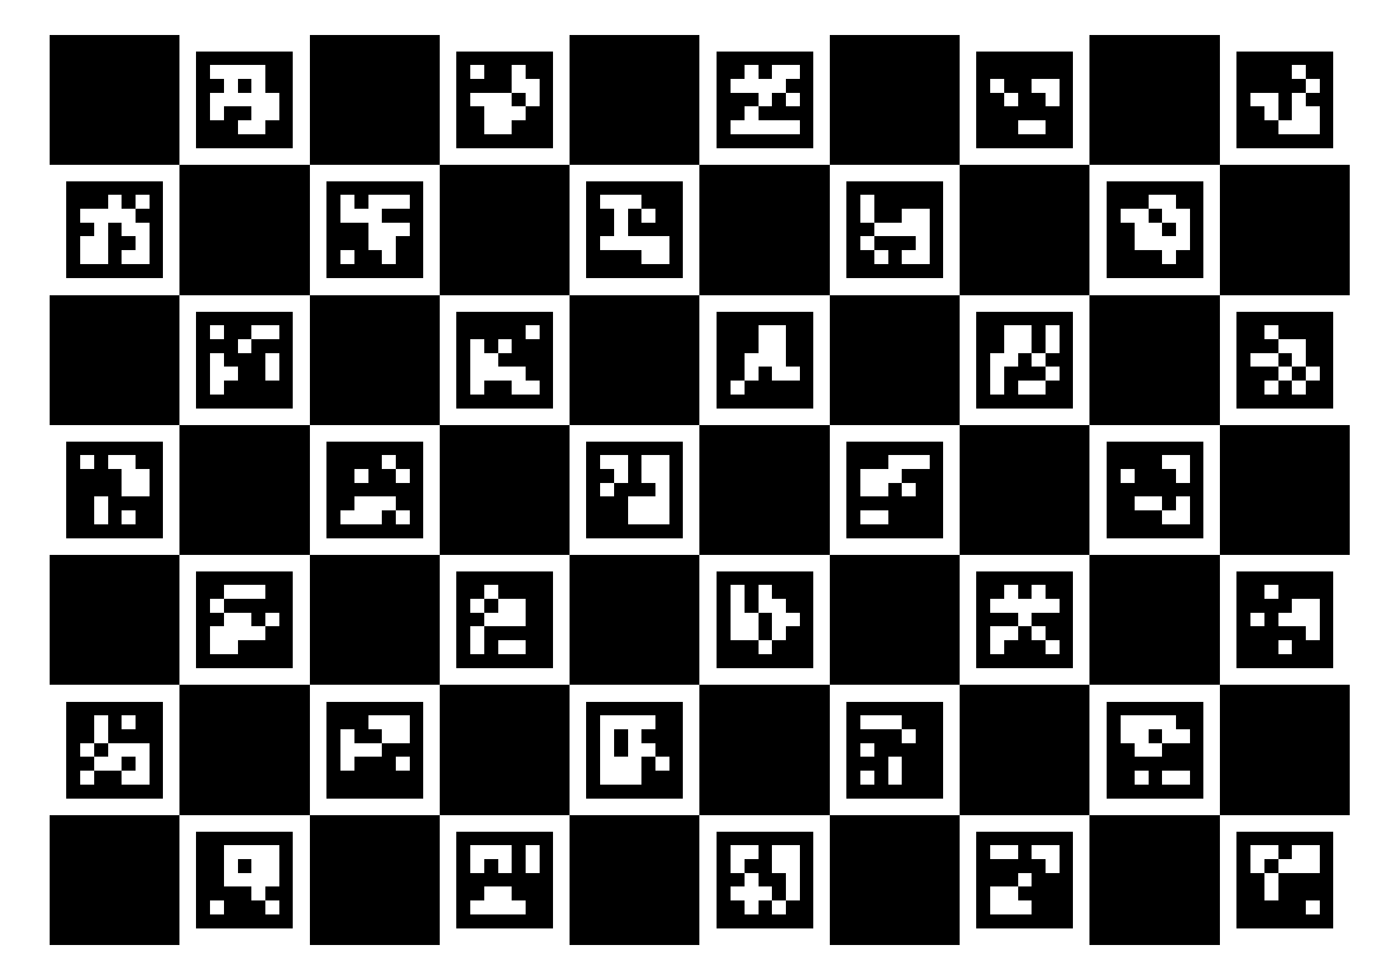
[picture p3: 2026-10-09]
calibration/charuco_board.png

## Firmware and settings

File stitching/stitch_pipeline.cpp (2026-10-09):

// stitch_pipeline.cpp - calibration-driven cylindrical stitch (C++), NO feature detection.
//
// Reads the Veery rig's calibration (cam0/cam1 fisheye intrinsics + stereo
// extrinsics from calibration/) and stitches the two camera feeds into a
// cylindrical panorama, aligning them from the extrinsic rotation R. No BRISK /
// matcher / findHomography anywhere.
//
// EVERY input is a PAIR - the rig writes one file per camera and this stitcher has
// no single-file mode. Pass EITHER file of a pair and its partner is found next to
// it, or give both explicitly as "cam0path::cam1path". See "dual input" below.
//
// The calibration must be FISHEYE (equidistant). The lenses are 110 deg with -16%
// barrel; a pinhole+polynomial fit leaves a uniform ~2.6px residual, so
// calibrate.py writes "model":"fisheye" and loadIntrinsics rejects anything else.
//
// Modes:
//   image source (.jpg/.png/...) -> stitch the one pose      -> pano.jpg
//   video source (.mp4/.mkv/...) -> loop frames [start..end] -> stitched_video.mp4
//   --tune  -> launch an interactive browser tuner (see below)
//
// cam1 alignment (folded into cam1's remap table, with the rotation and crop):
//   --shift-top N     horizontal shift of the TOP rows   (aligns the FAR edge)
//   --shift-bottom N  horizontal shift of the BOTTOM rows (aligns the NEAR edge)
//   --shift-y N       vertical shift of the whole image
// If top != bottom this is a vertical SHEAR: the per-row horizontal shift is
// interpolated between the two, so a receding field (near at the bottom, far at the
// top) lines up along a straight vertical seam. (--shift-x N sets top=bottom=N.)
//
// --tune warps the first frame once, starts a localhost web server, opens a browser
// to a live tuner where you adjust those values and click "Stitch all frames" to run
// the full stitch (progress bar + done). One command; UI opens itself.
//
// Video renders as a pipeline in ONE process (see FramePipeline): decode -> remap +
// exposure -> seam -> blend -> encode, several frames in flight, worker threads taking
// whichever stage has work. The smart seam is one continuous chain over the whole
// range, and there is a single output file - nothing to split or join.
//
// Two-file takes (the recorder writes one file per camera):
//   --source take_..._cam0.mkv   (or _cam1.mkv) finds the partner and pairs them in memory.
//   --pair-offset auto  (DEFAULT) takes the frame offset from the files' capture
//              timestamps when the recorder tagged them as one shared-clock take
//              (exact). Otherwise (older takes) it estimates it by
//              cross-correlating per-frame brightness over the first seconds - the same
//              method as pair_check.py, so no separate step is needed. Prints the
//              offset, its correlation and its margin. --pair-offset N pins a value
//              (0 disables). While the cameras FREE-RUN no single offset is right for a
//              whole take (they drift apart); with XVS genlock it is a true constant.
//
// Output size:
//   The panorama size is DERIVED from the calibration, not configured: the cylinder's
//   radius in pixels equals cam0's focal length, so the centre of frame is sampled
//   about 1:1. That is why the numbers look arbitrary (2104px focal -> 6774 wide).
//   --scale F  renders the cylinder at F times that radius: SAME field of view, fewer
//              pixels - it lowers pixel density, it does not crop (that is --crop).
//              Implemented by shrinking the radius before the maps are built, so the
//              frame is rendered once at the smaller size rather than downscaled after.
//   ffmpeg on PATH is the encode path (hardware HEVC/H.264); without it OpenCV's writer is used.
//
// Warp device: the stitching/warp always runs on the CPU (the OpenCL/GPU warp was
// measured slower - see the note in main). The video ENCODER still uses the GPU
// (hardware HEVC, chooseVideoEncoder). Uses core/imgproc/imgcodecs/videoio; OpenCV 4.x/5.x.
//
// --metadata-file F  stores the global tags of the ffmpeg FFMETADATA file F in the
//   output video (Studio uses it to record each stitch's settings in the file).
//
// Encoding (changed 2026-09-19): HEVC/H.265 at every size, tagged hvc1, with the
// bitrate defaulting to "auto" - sized from the output pixel rate at ~0.20 bpp rather
// than a fixed number, so a crop or a --scale gets a sensible rate by itself.
// --bitrate 90M still pins an explicit rate. H.264 remains only as a fallback.
//
// Build:  cmake -S . -B build && cmake --build build

#include <opencv2/core.hpp>
#include <opencv2/core/ocl.hpp>
#include <opencv2/imgproc.hpp>
#include <opencv2/imgcodecs.hpp>
#include <opencv2/videoio.hpp>
#include <iostream>
#include <fstream>
#include <filesystem>
#include <vector>
#include <cmath>
#include <string>
#include <sstream>
#include <iomanip>
#include <cstdlib>
#include <cstdio>
#include <algorithm>
#include <thread>
#include <atomic>
#include <mutex>
#include <condition_variable>
#include <future>
#include <functional>
#include <chrono>
#include <csignal>
#include "json.hpp"

#ifdef _WIN32
  #include <winsock2.h>
  #include <ws2tcpip.h>
  #include <windows.h>          // GetModuleFileNameA (locate our own exe)
  using socket_t = SOCKET;
  #define CLOSESOCK closesocket
#else
  #include <sys/socket.h>
  #include <netinet/in.h>
  #include <arpa/inet.h>
  #include <unistd.h>
  #include <fcntl.h>               // FD_CLOEXEC on child-process pipes
  using socket_t = int;
  #define CLOSESOCK close
  #define INVALID_SOCKET (-1)
#endif

#ifdef __APPLE__
  #include <mach-o/dyld.h>      // _NSGetExecutablePath (locate our own exe)
#endif

#ifdef _WIN32
  #define popen _popen
  #define pclose _pclose
  #define PIPE_WMODE "wb"        // binary: Windows text mode would mangle raw frames with CRLF
  #define PIPE_RMODE "rb"
#else
  #define PIPE_WMODE "w"         // POSIX popen only takes "r"/"w"; no 'b' flag
  #define PIPE_RMODE "r"
#endif

using json = nlohmann::json;
using namespace std;
using namespace cv;
namespace fs = std::filesystem;

static int runShell(string cmd);   // forward decl (defined near main); the encoder helpers below use it

// ---- video-encoder selection (set from CLI in main) ---------------------
// The stitch always re-encodes, so we hand raw frames to ffmpeg and let it use a
// hardware H.264 encoder when one is available - detected generically, not tied to
// any specific GPU. See chooseVideoEncoder().
static string g_vencExplicit;      // --venc NAME: force a specific encoder
static bool   g_forceCpu = false;  // --cpu / --no-hwenc: force software libx264
static string g_vbitrate  = "auto"; // --bitrate: explicit rate (e.g. "90M"), or "auto"
// --metadata-file: an ffmpeg FFMETADATA file whose global tags (Studio writes the
// stitch settings as JSON in "comment") are stored in the output video.
static string g_metaFile;
// "auto" sizes the bitrate from the OUTPUT pixel rate instead of a fixed number, so a
// crop, a --scale or a different rig all get a sensible rate without being re-tuned.
// Target bits-per-pixel: Joe's VMAF runs put good H.264 at ~0.26 bpp (25M on the old
// 2660x1199 pano). HEVC buys ~40% at equal quality, so 0.20 bpp HEVC sits a little
// ABOVE that validated point - right for a master that gets re-encoded downstream.
static double bppTarget(const string &venc)
{
    bool hevc = venc.find("hevc") != string::npos || venc.find("265") != string::npos;
    return hevc ? 0.20 : 0.30;
}
static string resolveBitrate(const string &venc, int W, int H, double fps)
{
    if (g_vbitrate != "auto") return g_vbitrate;
    if (fps <= 0) fps = 30.0;
    double bps = (double)W * H * fps * bppTarget(venc);
    long mbit = lround(bps / 1e6);
    mbit = max(8L, min(200L, mbit));          // sane floor/ceiling
    return to_string(mbit) + "M";
}

// A camera's projection model: maps cylinder points back to its source pixels.
struct CamModel
{
    double fx = 0, fy = 0, cx = 0, cy = 0;
    double r[9] = {1, 0, 0, 0, 1, 0, 0, 0, 1};   // camera-from-left rotation, row-major
    vector<double> D;
    int w = 0, h = 0;                            // source frame size
};

// The full cylindrical canvas: its geometry (so any canvas point can be re-projected
// into either camera) plus float remap tables over the whole canvas, which the tuner's
// live preview draws from.
struct StitchMaps
{
    Mat mapLx, mapLy, mapRx, mapRy;
    int OW = 0, OH = 0;
    int seam = 0;
    int ox0 = 0, ox1 = 0;   // overlap column range [ox0, ox1) where both cameras are valid
    CamModel camL, camR;
    double fcyl = 1, thetaMin = 0;   // canvas column x <-> angle thetaMin + x / fcyl
};

// The output view, in full-canvas coordinates: rotate the whole canvas by `degrees`
// (clockwise as shown) about its centre, then cut out the box. w/h <= 0 = whole canvas.
struct ViewBox
{
    int x = 0, y = 0, w = 0, h = 0;
    double degrees = 0;
};

// Per-render remap tables (see buildRenderMaps): shear + rotation + crop folded into
// ONE table per camera, so a frame is one remap per camera straight into output pixels.
// Each camera only covers the columns it can contribute to - left [0, sx1), right
// [sx0, OW) - where [sx0, sx1) is the strip the seam is blended across.
struct RenderMaps
{
    int OW = 0, OH = 0;           // output (crop box) size
    Mat mapL1, mapL2;             // left table over [0, sx1)   (fixed point)
    Mat mapR1, mapR2;             // right table over [sx0, OW) (fixed point)
    int sx0 = 0, sx1 = 0;         // blend strip (widest the seam can need)
    int margin = 0;               // blend reach either side of the seam (from the band count)
    int bx0 = 0, bx1 = 0;         // seam band: columns where both cameras overlap on some row
    Mat overlap;                  // CV_8U over the band: 1 where both cameras are valid
    vector<float> home;           // per row: the seam's home column in output coordinates
};

// Right-image alignment (per-row horizontal shear + vertical shift) + seam blend.
struct Align
{
    double shiftTop = 0, shiftBottom = 0, shiftY = 0;
    int bands = 0;       // multi-band (Laplacian) blend levels; 0 = hard seam
    bool exposure = false; // match right image brightness/color to left (per channel)
    bool smartSeam = false; // route the seam around moving objects (min-difference path)
};

// Shared progress state for the --tune server (stitch runs on a worker thread).
static std::atomic<int> g_percent{0};
static std::atomic<bool> g_busy{false};
static std::atomic<bool> g_done{false};
static std::mutex g_mu;
static string g_result;
// The exact equivalent CLI command for the last/active stitch (shown in the tuner UI
// and console) so you can reproduce a tuned render manually.
static string g_cmd;

// The rig's CIL391 lenses (110 deg, -16% barrel) are fisheyes and only fit the
// equidistant model - a pinhole+polynomial fit leaves a uniform ~2.6px residual.
// calibrate.py therefore writes "model":"fisheye" into every intrinsics file and
// this stitcher accepts nothing else: a mismatched model does not fail loudly, it
// silently yields a plausible-looking panorama built from the wrong projection.
static void loadIntrinsics(const string &path, Mat &K, vector<double> &D)
{
    ifstream f(path);
    if (!f.is_open()) { cerr << "Cannot open " << path << endl; exit(1); }
    json j; f >> j;
    if (!j.contains("model") || j["model"].get<string>() != "fisheye")
    {
        cerr << "ERROR: " << path << " is not a fisheye calibration "
             << "(missing \"model\": \"fisheye\").\n"
             << "       This stitcher is equidistant-only. Re-solve it with "
             << "calibration/calibrate.py.\n";
        exit(1);
    }
    K = Mat::eye(3, 3, CV_64F);
    for (int r = 0; r < 3; r++)
        for (int c = 0; c < 3; c++)
            K.at<double>(r, c) = j["camera_matrix"][r][c].get<double>();
    D.clear();
    for (auto &v : j["distortion_coefficients"])
        D.push_back(v.get<double>());
}

static Mat loadRotation(const string &path)
{
    ifstream f(path);
    if (!f.is_open()) { cerr << "Cannot open " << path << endl; exit(1); }
    json j; f >> j;
    Mat R(3, 3, CV_64F);
    for (int r = 0; r < 3; r++)
        for (int c = 0; c < 3; c++)
            R.at<double>(r, c) = j["rotation_matrix"][r][c].get<double>();
    return R;
}

// Equidistant (Kannala-Brandt) projection: radius grows with the ANGLE, not its
// tangent, which is what a fisheye lens actually does. Mirrors cv::fisheye.
static inline void applyFisheye(double x, double y, const vector<double> &D,
                                double &xd, double &yd)
{
    double k1 = D.size() > 0 ? D[0] : 0, k2 = D.size() > 1 ? D[1] : 0;
    double k3 = D.size() > 2 ? D[2] : 0, k4 = D.size() > 3 ? D[3] : 0;
    double r = sqrt(x * x + y * y);
    if (r < 1e-12) { xd = x; yd = y; return; }
    double th = atan(r);
    double t2 = th * th;
    double thd = th * (1 + k1 * t2 + k2 * t2 * t2 + k3 * t2 * t2 * t2 + k4 * t2 * t2 * t2 * t2);
    double scale = thd / r;
    xd = x * scale;
    yd = y * scale;
}

static CamModel camModel(const Mat &K, const vector<double> &D, const Mat &R_cam_from_left, int w, int h)
{
    CamModel c;
    c.fx = K.at<double>(0, 0); c.fy = K.at<double>(1, 1);
    c.cx = K.at<double>(0, 2); c.cy = K.at<double>(1, 2);
    for (int i = 0; i < 9; i++) c.r[i] = R_cam_from_left.at<double>(i / 3, i % 3);
    c.D = D; c.w = w; c.h = h;
    return c;
}

// Cylinder point (angle th, height hh) -> source pixel (u, v) of one camera. False if
// the ray is behind the camera or lands outside its frame.
static inline bool cylToCam(const CamModel &c, double th, double hh, float &u, float &v)
{
    double dx = sin(th), dy = hh, dz = cos(th);
    const double *r = c.r;
    double cxr = r[0] * dx + r[1] * dy + r[2] * dz;
    double cyr = r[3] * dx + r[4] * dy + r[5] * dz;
    double czr = r[6] * dx + r[7] * dy + r[8] * dz;
    if (czr <= 1e-6) return false;
    double xd, yd;
    applyFisheye(cxr / czr, cyr / czr, c.D, xd, yd);
    double uu = c.fx * xd + c.cx, vv = c.fy * yd + c.cy;
    if (uu < 0 || uu >= c.w || vv < 0 || vv >= c.h) return false;
    u = (float)uu; v = (float)vv;
    return true;
}

static void buildCylMap(const CamModel &c, const vector<double> &theta, const vector<double> &hval,
                        Mat &mapx, Mat &mapy, Mat &valid)
{
    int OW = (int)theta.size(), OH = (int)hval.size();
    mapx.create(OH, OW, CV_32F);
    mapy.create(OH, OW, CV_32F);
    valid = Mat::zeros(OH, OW, CV_8U);
    parallel_for_(Range(0, OH), [&](const Range &rows) {
        for (int yy = rows.start; yy < rows.end; yy++)
        {
            float *mx = mapx.ptr<float>(yy), *my = mapy.ptr<float>(yy);
            uchar *vv = valid.ptr<uchar>(yy);
            for (int xx = 0; xx < OW; xx++)
            {
                if (cylToCam(c, theta[xx], hval[yy], mx[xx], my[xx])) vv[xx] = 1;
                else mx[xx] = my[xx] = -1.f;
            }
        }
    });
}
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
int main(int argc, char **argv)
{
#ifndef _WIN32
    // If the ffmpeg encoder pipe dies, we want fwrite to fail (handled) rather than a
    // SIGPIPE killing us silently. (Windows has no SIGPIPE.)
    signal(SIGPIPE, SIG_IGN);
#endif
    string source = argVal(argc, argv, "--source", argVal(argc, argv, "--image", ""));
    string calibDir = resolveCalibDir(argVal(argc, argv, "--calib-dir", "../calibration"));
    string outDir = argVal(argc, argv, "--out", "pipeline_out");
    string outFile = argVal(argc, argv, "--out-file", "");   // full path incl. filename (overrides --out)
    double degrees = stod(argVal(argc, argv, "--degrees", "0"));
    int seamArg = stoi(argVal(argc, argv, "--seam", "-1"));
    int startFrame = stoi(argVal(argc, argv, "--start", "0"));
    int endFrame = stoi(argVal(argc, argv, "--end", "-1"));
    string sx = argVal(argc, argv, "--shift-x", "0");   // convenience: sets top=bottom
    Align a;
    a.shiftTop = stod(argVal(argc, argv, "--shift-top", sx));
    a.shiftBottom = stod(argVal(argc, argv, "--shift-bottom", sx));
    a.shiftY = stod(argVal(argc, argv, "--shift-y", "0"));
    a.bands = stoi(argVal(argc, argv, "--bands", "6"));   // 0 = hard seam
    a.exposure = !hasArg(argc, argv, "--no-exposure");     // on by default
    a.smartSeam = !hasArg(argc, argv, "--no-smart-seam");  // on by default
    int port = stoi(argVal(argc, argv, "--port", "8090"));
    bool tune = hasArg(argc, argv, "--tune");
    string cropArg = argVal(argc, argv, "--crop", "");
    {   // --pair-offset N pins the offset; "auto" (the default) estimates it
        string po = argVal(argc, argv, "--pair-offset", "auto");
        if (po != "auto") { g_pairOffset = stoi(po); g_pairAuto = false; g_pairResolved = true; }
    }
    g_scale = stod(argVal(argc, argv, "--scale", "1.0"));
    if (g_scale <= 0.05 || g_scale > 1.0) { cerr << "--scale must be in (0.05, 1]\n"; return 1; }

    // Video-encoder selection (globals consumed by chooseVideoEncoder / stitchVideoFile).
    // --cpu / --no-hwenc force libx264; --venc names a specific encoder; --bitrate sets -b:v.
    g_forceCpu   = hasArg(argc, argv, "--cpu") || hasArg(argc, argv, "--no-hwenc");
    g_vencExplicit = argVal(argc, argv, "--venc", "");
    g_vbitrate   = argVal(argc, argv, "--bitrate", "auto");
    g_metaFile   = argVal(argc, argv, "--metadata-file", "");

    // Ensure the output destination exists (batch, or a preset --out-file).
    if (!outFile.empty()) { fs::path p(outFile); if (p.has_parent_path()) fs::create_directories(p.parent_path()); }
    else fs::create_directories(outDir);

    // Stitching/warp ALWAYS runs on the CPU: the OpenCL/GPU warp was measured slower
    // (a memory-bound remap sandwiched between CPU decode and CPU encode pays a
    // per-frame CPU<->GPU copy that outweighs the GPU speedup). The video ENCODER
    // still uses the GPU (hardware H.264, with a libx264 fallback - chooseVideoEncoder).
    ocl::setUseOpenCL(false);
    cout << "OpenCL available: " << ocl::haveOpenCL() << ", using GPU (warp): " << ocl::useOpenCL() << "\n";

    cout << "Calibration: " << calibDir << "\n";
    Mat KL, KR, R;
    vector<double> DL, DR;
    loadIntrinsics(calibDir + "/cam0_intrinsics.json", KL, DL);
    loadIntrinsics(calibDir + "/cam1_intrinsics.json", KR, DR);
    cout << "calibration model: fisheye (equidistant)\n";
    R = loadRotation(calibDir + "/stereo_extrinsics.json");
    g_noAlign = hasArg(argc, argv, "--no-align");
    if (!source.empty() && !tune)
    {
        TakeAlign ta = loadTakeAlign(source);
        if (ta.ok)
        {
            R = ta.R;
            cout << "alignment: " << ta.path << " (this take's rotation)\n";
            if (!hasArg(argc, argv, "--shift-top") && !hasArg(argc, argv, "--shift-bottom")
                && !hasArg(argc, argv, "--shift-x"))
            {
                a.shiftTop = ta.shiftTop; a.shiftBottom = ta.shiftBottom;
                cout << "shear from the take's alignment: " << a.shiftTop << " / " << a.shiftBottom << "\n";
            }
        }
    }
    // cam1 left of cam0 (negative yaw) -> run with cam1 as the left image. R maps
    // cam0-frame directions into cam1's frame; the reverse mapping is its transpose.
    if (atan2(R.at<double>(2, 0), R.at<double>(2, 2)) < 0)
    {
        g_swapLR = true;
        std::swap(KL, KR);
        std::swap(DL, DR);
        R = R.t();
        cout << "orientation: cam1 is the LEFT camera (from the extrinsics) - "
             << "stitching cam1|cam0\n";
    }

    // Interactive tuner — the default when no --source is given, and whenever
    // --tune is passed. The browser's Import button loads the source on demand,
    // so `source` may be empty here (empty page until the user imports).
    if (source.empty() || tune)
    {
        runTuneServer(KL, DL, KR, DR, R, degrees, startFrame, endFrame, outDir, source, outFile, port, calibDir);
        return 0;
    }

    // Headless batch stitch of a source given on the command line.
    bool video = isVideoFile(source);
    Mat fL, fR;
    int totalFrames = 1;
    if (!video) readPairedImage(source, fL, fR);
    else
    {
        PairCapture cap(source);
        if (cap.isOpened())
        {
            totalFrames = (int)cap.get(CAP_PROP_FRAME_COUNT);
            // some containers (e.g. MJPEG-in-MKV) don't report a valid count;
            // fall back to ffprobe (duration x fps), or 0 -> typeable frame box.
            if (totalFrames < 1 || totalFrames > 100000000)
            {
                double fps = cap.get(CAP_PROP_FPS);
                totalFrames = probeFrames(source, fps > 0 ? fps : 30.0);
            }
            if (startFrame > 0) seekFrame(cap, startFrame);
            cap.read(fL, fR);
            cap.release();
        }
    }
    if (fL.empty() || fR.empty()) { cerr << "Cannot read source: " << source << endl; return 1; }

    StitchMaps m = buildStitchMaps(KL, DL, KR, DR, R, fL.cols, fL.rows, seamArg);

    // Optional --crop "x,y,w,h" (full-canvas coords) and --degrees: rotate the whole
    // panorama, then crop - folded with cam1's shear into one table per camera
    // (see buildRenderMaps).
    ViewBox vb;
    vb.degrees = degrees;
    if (!cropArg.empty()
        && sscanf(cropArg.c_str(), "%d,%d,%d,%d", &vb.x, &vb.y, &vb.w, &vb.h) == 4 && vb.w > 0 && vb.h > 0)
        cout << "crop " << vb.w << "x" << vb.h << " @ (" << vb.x << "," << vb.y << ")\n";
    RenderMaps rm = buildRenderMaps(m, vb, a);
    if (degrees != 0.0)
        cout << "rotate " << degrees << " deg (clockwise), then crop -> " << rm.OW << "x" << rm.OH << "\n";

    string result = video ? stitchVideoFile(source, rm, a, startFrame, endFrame, totalFrames, outDir, outFile, nullptr)
                          : stitchImageFile(source, rm, a, outDir, outFile);
    cout << (video ? "video -> " : "image -> ") << result << "\n";
    return 0;
}

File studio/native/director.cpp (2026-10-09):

// director.cpp - renders a Director edit: the virtual-camera cut of a stitched panorama.
//
// The edit itself is made in Studio's editor page (studio/, /edit/<video>):
//   1. Cut   - mark each point of the game with In / Out.
//   2. Frame - per point, steer a 16:9 box over the full-width panorama while it
//              plays. One take covers the whole point (In..Out).
// The page saves the edit next to the video (<video>.director.json). This program
// renders it: it crops the box out of every frame of every point and encodes the
// result at the output size (default 2560x1440) - one video with the points in
// order, or one file per point. Studio runs it as a render job.
//
// Usage:
//   Director --render project.json --out edit.mp4 [--video stitched.mp4] [--per-point]
//            [--unframed skip|wide] [--codec h264|hevc] [--quality high|standard]
// Progress goes to stderr every 2 s ("  cur/total frames  point"), the output
// path(s) to stdout. Needs ffmpeg + ffprobe on PATH (frame-accurate decode, encode).

#include <opencv2/core.hpp>
#include <opencv2/imgproc.hpp>
#include <iostream>
#include <fstream>
#include <sstream>
#include <filesystem>
#include <vector>
#include <string>
#include <thread>
#include <mutex>
#include <atomic>
#include <cmath>
#include <cstdio>
#include <csignal>
#include <algorithm>
#include <iomanip>
#include <cctype>
#include <chrono>
#include <map>
#include <ctime>
#include "json.hpp"


using json = nlohmann::json;
using namespace std;
namespace fs = std::filesystem;

// ---------------------------------------------------------------- small helpers

static string runCapture(const string &cmd)
{
    string out;
    FILE *p = popen(cmd.c_str(), "r");
    if (!p) return "";
    char buf[4096]; size_t n;
    while ((n = fread(buf, 1, sizeof(buf), p)) > 0) out.append(buf, n);
    pclose(p);
    while (!out.empty() && (out.back() == '\n' || out.back() == '\r')) out.pop_back();
    return out;
}

static string q(const string &s) { return "\"" + s + "\""; }

static string devNull()
{
    return " >/dev/null 2>&1";
}

static string argVal(int argc, char **argv, const string &key, const string &def)
{
    for (int i = 1; i < argc - 1; i++) if (key == argv[i]) return argv[i + 1];
    return def;
}
static bool hasArg(int argc, char **argv, const string &key)
{
    for (int i = 1; i < argc; i++) if (key == argv[i]) return true;
    return false;
}

// ---------------------------------------------------------------- video + project

struct VideoInfo
{
    string path;
    int width = 0, height = 0, frames = 0;
    double fps = 30.0;
    bool fullRange = false;        // "pc" range: black is Y=0 instead of 16
    bool ok() const { return width > 0 && height > 0 && frames > 0; }
};

// Exact size / rate / frame count from the container (ffprobe), falling back to a
// counted decode when the container doesn't record nb_frames.
static VideoInfo probeVideo(const string &path)
{
    VideoInfo v; v.path = path;
    string out = runCapture("ffprobe -v error -select_streams v:0 -show_entries "
                            "stream=width,height,r_frame_rate,nb_frames,color_range -of json " + q(path));
    try
    {
        json j = json::parse(out);
        auto &s = j.at("streams").at(0);
        v.width = s.value("width", 0); v.height = s.value("height", 0);
        string r = s.value("r_frame_rate", "30/1");
        size_t sl = r.find('/');
        double num = stod(r.substr(0, sl)), den = sl == string::npos ? 1.0 : stod(r.substr(sl + 1));
        if (den > 0) v.fps = num / den;
        if (s.contains("nb_frames")) v.frames = stoi(s["nb_frames"].get<string>());
        v.fullRange = s.value("color_range", string()) == "pc";
    }
    catch (...) { return v; }
    if (v.frames <= 0)
    {
        string c = runCapture("ffprobe -v error -count_frames -select_streams v:0 -show_entries "
                              "stream=nb_read_frames -of csv=p=0 " + q(path));
        try { v.frames = stoi(c); } catch (...) {}
    }
    return v;
}

static string readFile(const string &path)
{
    ifstream f(path, ios::binary);
    if (!f) return "";
    ostringstream s; s << f.rdbuf(); return s.str();
}

// ---------------------------------------------------------------- render

struct RenderOpts
{
    string out;                 // output file (or base name with --per-point)
    bool perPoint = false;      // one file per point instead of one video
    bool unframedWide = false;  // unframed points: left out by default (or a wide shot)
    string codec = "h264";      // "h264" (plays everywhere) | "hevc" (same quality, smaller)
    string quality = "high";    // "high" | "standard"
};

struct Progress
{
    std::mutex mu;
    long long total = 0, cur = 0;
    string msg;
};
static Progress g_prog;

static bool encoderWorks(const string &enc)
{
    return system(("ffmpeg -hide_banner -loglevel error -f lavfi -i color=c=black:s=256x144:d=0.1 "
                   "-c:v " + enc + " -f null -" + devNull()).c_str()) == 0;
}

// The output is a normal 16:9 video (<= 4096 wide), so hardware H.264 fits and plays
// everywhere. Bitrate ~0.3 bits/pixel: 2560x1440@30 -> ~33 Mbit/s.
static string g_vencOverride, g_vencOpts;   // --venc / --vopts (testing and power use)
static bool g_fullRange = false;            // source range, carried through to the output tag

// Encoder per codec: hardware where it works (VideoToolbox on a Mac, NVENC elsewhere),
// else the software encoder. Checked once per name.
static string pickEncoder(const string &codec)
{
    static map<string, string> cache;
    auto it = cache.find(codec);
    if (it != cache.end()) return it->second;
    bool hevc = codec == "hevc";
#ifdef __APPLE__
    string hw = hevc ? "hevc_videotoolbox" : "h264_videotoolbox";
#else
    string hw = hevc ? "hevc_nvenc" : "h264_nvenc";
#endif
    string enc = encoderWorks(hw) ? hw : (hevc ? "libx265" : "libx264");
    cache[codec] = enc;
    return enc;
}
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

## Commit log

2026-09-19 stitch: HEVC at every size, hvc1 tag, and a resolution-aware bitrate
    Encoder: HEVC is now first choice at all sizes rather than a >4096 fallback.
    Measured on the M5 Pro: at equal size HEVC costs ~6% against H.264 (88.5 vs
    93.7 fps at 4096x1433) and buys ~40% in bits; at the real 6774x2371 pano it runs
    34.9 fps, still faster than realtime, and H.264 hardware refuses the frame
    entirely (h264_videotoolbox is fine to 4096x2371, fails at 4224 wide with
    -12903 - the cap is WIDTH, height is not a constraint). H.264 stays as a
    fallback for machines whose HEVC block refuses the frame.
    Tag: HEVC in MP4 was being written as 'hev1', which QuickTime, Safari and some
    Resolve builds will not open. Now tag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
    [stitch_pipeline.cpp]
2026-09-20 iq: shutter-only AE at unity gain, floor lowered to the 4-line hardware min
    Joe's call. Two changes to the AE route:
    Unity gain throughout - GainDot is now [1,1,1,1,1,1] instead of reaching 2.0
    in the darkest scenes. That stop of brightness cost a stop of noise, and this
    rig only shoots lit fields; when 33ms at gain 1.0 runs out of light the frame
    is simply dark, which is the accepted trade.
    Floor lowered 500us -> 53.3us, the sensor's real minimum (IMX477_EXPOSURE_MIN
    = 4 lines x 13.333us line time). The old floor was never measured - it came
    from an assumed "sun ~1ms" - and left ~3.2 stops of the sensor's range
    unreachable, which is a plausible cause of a sunlit field clipping while AE
    si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
2026-09-20 driver: power-on analog gain default to unity (was 2.0x)
    IMX477_GAIN_DEFAULT was 0x20 = 2.0x, so the sensor powered on a full stop
    hot before rkaiq took over. This rig is daylight-only and never wants
    amplification, so unity (0x10) is the right reset state.
    Exposure needed no change: V4L2_CID_EXPOSURE is already registered across the
    sensor's full range, IMX477_EXPOSURE_MIN (4 lines = 53.3us) to vts_def-22
    (2478 lines = 33.0ms). The 500us floor that was actually limiting AE lived in
    the IQ route, not here, and was lowered in 5ca3ca1.
    GAIN_MAX deliberately left at 22.26x. The driver is built into the kernel, so
    anything encoded here costs a kernel rebuild to revisit; capability belongs in
    t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
    [imx477.c]
2026-09-20 panel: browse and delete the mounted drive, and show sync state per take
    Manage Files only ever showed the Rock's own recordings, so after copying to
    the USB drive there was no way to see what had actually landed, or to clear
    space on the drive, without a terminal.
    The takes table gains an "On drive" column: copied / not copied / size differs.
    "Copied" means same name and same byte count - a size check, not a checksum,
    which is what the transfer itself already verifies; hashing a 25 GB take would
    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
2026-09-21 branch cleanup: remove Orin-era code, fisheye-only pipeline
    [Rock Housing - Bottom.3mf, Rock Housing - Bottom.stl, Rock Housing - Top.3mf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]
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2026-09-22 flatten calibration/rock-rig into calibration/; merge WORKFLOW into README; prune stale hardware-log sections
2026-10-02 imx477: single genlock switch; veery panel: /calib snapshot page
    Driver: replace the trigger_mode override (defaulted to 0, which forced
    free-run over the DT roles) with one bool param, genlock (default 1):
    1 = sensors take their DT source/sink roles, 0 = all free-run. Built and
    running on the Rock as kernel -6.
    Panel: /calib page with the live previews and a Take Snapshot button that
    captures both mainpaths together (works in sync mode), lets them settle
    ~1.5s, and saves cam0_NNN.png + cam1_NNN.png to ~/calib-pairs, all or
    nothing so the numbering always stays paired.
    [imx477.c]
2026-10-02 Rotate everything saved or shown 180 deg (cameras mounted upside down)
    The sensors read out as they are; recording (mpph265enc rotation=180),
    panel previews (videoflip), /calib snapshots, calib_server.py and
    snap_pair.sh all rotate 180, so files on disk are upright.
    Calibration converted once with the new calibration/rotate180.py:
    cx -> W-1-cx, cy -> H-1-cy (f and fisheye D unchanged), extrinsics
    R -> F R F, T -> F T with F = diag(-1,-1,1). Files are marked
    "orientation": "rot180" so a second run is a no-op.
    Stitcher: when the extrinsic yaw puts cam1 left of cam0 it swaps the
    pair (cam1|cam0, R transposed). --pair-offset and printed offsets stay
    in cam0/cam1 terms. Verified on an image pai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
    [stitch_pipeline.cpp]
2026-10-03 calibration: swap cam0/cam1 intrinsics to match the cameras' current ports
    The cameras were re-plugged after the intrinsics were solved. Matched
    features in a /calib pair (284 inliers in the overlap) fit far better
    with the files swapped: relative tilt 1.6 deg vs 6.7 deg, baseline
    almost purely horizontal (|t_y| 0.02 vs 0.11), epipolar error 0.42 vs
    0.67 px, yaw ~74.8 deg (design 74). cam0_intrinsics.json now belongs to
    the camera on the CAM0 port (i2c3, m00).
2026-10-03 calibration: fisheye-aware stereo solve; first housed extrinsics
    calibrate.py's extrinsics step still called cv2.stereoCalibrate with the
    fisheye coefficients, which it reads as pinhole k1,k2,p1,p2 - on good
    /calib pairs that gave 28 px RMS and a 2.8 deg "toe-in". Corners are now
    mapped through each camera's fisheye model to normalized coordinates and
    the pose is solved there (identity camera, no distortion); RMS is
    reported in real fisheye pixels. The pinhole rectified sample is replaced
    by stereo_reprojection_sample.jpg (detected vs predicted corners). New
    JSONs carry "orientation": "rot180" so rotate180.py never re-converts.
    stereo_extrinsics.json: first real solve in the housing, 26 /ca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
2026-10-03 Record both cameras in one pipeline; pair offset from capture timestamps
    Recorder: one gst-launch with a branch per camera instead of two
    processes - one clock and base time, so genlocked frames get the same
    timestamps in both files. videorate skip-to-first=true starts each file at
    its first real frame (no frozen filler), matroskamux offset-to-zero=false
    keeps that real start time, and taginject writes COMMENT=veery-shared-clock.
    Trade-off (deliberate): a fault in one camera ends the take.
    Stitcher and pair_check.py: for tagged takes the offset is
    -(start1 - start0) * fps, exact, with a residual check (> 1/4 frame warns
    that the cameras do not look genlocked). Untagged takes fall back to th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
    [stitch_pipeline.cpp]
2026-10-03 Panel: previews and snapshots as one gst process each (branch per camera), matching recording
2026-10-03 Shared-clock tag: also search stream tags
    matroskamux stores taginject's comment on the video track (COMMENTS in the
    stream tags), not at file level. First real take: cam0 starts 0.039s,
    cam1 0.005s -> offset +1 frame, off-grid residual -0.02 frame (genlocked);
    frame counts 241/242 agree.
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2026-10-03 kernel-build: reproducible Docker build on any machine; pin source + config
    - kernel.config: the exact kernel settings (the Rock's config + IMX477 built
    in + -8-rk2410-imx477 suffix), previously only inside a local container
    - build-kernel-docker.sh: builds the .debs in a Debian container on any
    Docker host (native on arm64, cross-compiles on x86-64); Radxa source
    pinned to 34337a9c76fd (linux-6.1-stan-rkr4.1, 6.1.84); source + objects
    kept in a Docker volume so rebuilds are incremental
    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
2026-10-03 Stitcher: either file of a pair, output chooser + live command, rotate-then-crop, no audio
    - Pairing: either half of a pair works (take_..._cam0/_cam1.mkv and the
    /calib page's cam0_/cam1_NNN.png); choosing cam1 used to fail. Same in
    pair_check.py. A missing partner names the missing file.
    - Tuner: Output -> Choose... picks the file up front and shows the
    equivalent CLI command, kept in step with every change, without
    stitching (Stitch reuses it or asks). Layout: output, shifts, rotate,
    show seam + crop, overlap blend, frame seeker. Seam control and seam
    dragging removed - the seam is the middle of the overlap.
    - Query parser matched keys by substring ("seam=" inside "smartseam=1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
    [stitch_pipeline.cpp]
2026-10-03 3d-housing-model: updated top/bottom housing, add print-oriented STLs
    [Rock Housing - Bottom - PRINT ORIENTED.stl, Rock Housing - Bottom.3mf, Rock Housing - Bottom.stl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]
2026-10-03 Stitcher: single-remap render, integer blend, in-process frame pipeline
    - Shear, rotation and crop folded into one remap table per camera
    (buildRenderMaps): one resample per frame, only the output box rendered,
    seam home line carried through the rotation so it stays camera-relative.
    - Each camera remapped only over the columns it contributes; fixed-point
    remap tables; left/right frames passed separately (no hconcat/split copies).
    - Blend only around this frame's seam path; 16-bit integer Laplacian blend
    with a fused per-level mask pass and a threaded pyrUp.
    - Video renders through an in-process pipeline (decode -> remap+exposure ->
    seam -> blend -> encode; ordered/parallel stages,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
    [stitch_pipeline.cpp]
2026-10-03 Calibration: correct cam1 tilt/roll from footage; tuner vertical shift control
    - stereo_extrinsics.json: rotation corrected on real footage (take_20261003_133914,
    frames 0 and 3000) so cam1 lines up vertically with cam0: pitch -0.29 deg at the
    seam, roll +1.37 deg about the seam direction. Yaw left as solved; parallax stays
    with the shear. Vertical error 12-23 px -> ~0.2 px; shear for this scene
    -14/+48 -> +14/+20.5. Original matrix kept under scene_refinement.
    - Tuner: "Shift vertical" control next to the shear (preview + stitch + CLI command).
    - README: scene-refinement notes.
    [stitch_pipeline.cpp]
2026-10-03 Calibration: parallax-free yaw/roll refinement; drop tuner vertical shift
    - stereo_extrinsics.json re-refined from the board solve using only
    parallax-free measurements: pitch -0.290 deg (vertical offset at the seam),
    roll +1.240 deg (across-overlap vertical slope with the parallax term fitted
    out), yaw -0.401 deg (horizontal offset on the far field below the horizon).
    The cameras now agree for a scene at infinity; the shear carries only
    parallax (test position: -3 / +8.4, shift-y 0). Original matrix and method
    recorded under scene_refinement.
    - Tuner: remove the "Shift vertical" control again (no longer needed; the CLI
    --shift-y flag remains).
    - README: updated scene-refinemen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
    [stitch_pipeline.cpp]
2026-10-04 Director (virtual-camera editor) + correct camera colour decoding
    Director (stitching/director.cpp + director.html, launched by director.command/.bat):
    - Cut the game into points (I/O), then steer a 16:9 box over each point while it
    plays; one take per point, smoothed (zero-lag Gaussian + dead-band). Zoom readout,
    1:1 reset, letterboxed wide shots. Takes are protected: never undone, older takes
    kept per point ("Previous take"). Autosave to <video>.director.json with
    timestamped backups.
    - Render: frame-exact decode -> per-plane bicubic crop in native YUV 4:2:0 (no
    colour conversion; a 1:1 box is a bit-exact crop) -> H.264/HEVC. One video or one
    file per point; unframed points lef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
    [director.cpp, stitch_pipeline.cpp]
2026-10-09 calibration: refine_extrinsics.py - check/correct camera alignment from footage
    --check measures, on any take, the vertical offset at the seam, the vertical tilt
    across the overlap (far rows) and the far-field horizontal offset with the current
    calibration, prints the shear for that rig position and a verdict. --apply solves
    the small tilt/roll/yaw correction from those parallax-free measurements only,
    backs up stereo_extrinsics.json, writes the new rotation with a
    refinement_history entry and re-measures. README: routine per-session check.
2026-10-09 Per-take alignment files: refine_extrinsics --align, stitcher picks them up
    - refine_extrinsics.py --align (default workflow) writes take_TS.align.json next
    to the take: absolute cam0->cam1 rotation plus measured shear (shift_top /
    shift_bottom). --check uses the take's file unless --base; --apply still
    updates the base calibration (with a .bak and history entry).
    - StitchPipeline (CLI and --tune) uses the take's align file when present,
    otherwise the base calibration; shear defaults to the file's values unless
    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
2026-10-09 Veery Studio: one local web app to align, stitch and edit a folder of takes
    studio/ (own venv: requirements.txt, setup.sh, studio.command):
    - server.py: takes list (camera pairs + stitched videos), /stitch/<take>,
    /edit/<video>; long work runs as jobs (one process each, polled via
    /api/jobs): align x2 queued, stitch x1, render x1; cancel kills the
    process group and removes a partial stitch. Logs to studio/studio.log.
    - Stitch page: the tuner's controls on any frame; preview is the stitcher's
    warp recomputed in Python (rig.py/preview.py), checked against
    StitchPipeline output (same canvas/seam, same frame index).
    - Stitched videos record their settings as JSON in the MP4 comment tag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
    [stitch_pipeline.cpp]
2026-10-09 Repo cleanup: one Studio app, one venv, a self-installing Rock, a flashable Rock image
    Mac side
    - stitching/ folded into studio/native/: StitchPipeline and Director are now
    command-line tools only (the old tuner and Director web servers are gone -
    Studio is the UI). director.html, launchers, pair_check.py removed.
    - One Python environment at the repo root: ./setup.sh creates .venv from
    requirements.txt and builds studio/native; studio.command uses it.
    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
    [Rock Housing - Bottom - PRINT ORIENTED.stl, Rock Housing - Top - PRINT ORIENTED.stl]
2026-10-09 Rock network setup from camera-network.txt (Wi-Fi first, then the hotspot)
    The image ships /config/camera-network.txt (the card's config partition, editable on a
    Mac after flashing); camera-network.service applies it once at the next boot and renames
    it camera-network.applied.txt with the passwords blanked:
    - WIFI_NAME + WIFI_PASSWORD (both required): autoconnect priority 100
    - HOTSPOT_NAME (default VeeryCam, password changeme123; blank password = open):
    2.4 GHz access point at 10.43.0.1/24, priority -10
    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
2026-10-09 Rock image: type the config partition as a data partition so Macs/PCs mount it
    Radxa's layout types it "Linux filesystem", so macOS never shows the config drive where
    camera-network.txt is edited. The Rock mounts it by filesystem UUID, unaffected.
2026-10-09 Rock Wi-Fi: scan, join a known network, otherwise the hotspot (wifi-fallback)
    A self-starting hotspot won the race against the radio's first scan at boot, so the Rock
    came up on VeeryCam even at home (and an access point can't scan, so it stayed there
    until KDE's applet rescanned at a desktop login). Now the hotspot does not autoconnect;
    wifi-fallback.service runs at every boot: one scan, connect to the best known network in
    range, and start the hotspot only if that fails or none is in range - no fixed waits.
    Tested on the Rock: joined home Wi-Fi 15 s after power-on, no login needed.
2026-10-09 Releases: kernel-1 and a mirror of Radxa's base image; builds need nothing outside the repo
    - The camera kernel is republished as kernel-1 (package revision 1, same kernel as the
    former kernel-6, which is removed); setup.sh KREV=1, docs updated.
    - Radxa's rsdk-r7 image is mirrored unmodified as release radxa-rsdk-r7 (checked against
    Radxa's checksum); the image build downloads it from there instead of Radxa.
    - kernel-build: REV is documented as the kernel's number (= release kernel-REV);
    the obsolete "remove the stock-kernel workaround" section and Windows mentions removed.
2026-10-09 setup.sh: install the camera kernel over a held one (--force-hold)
    The kernel packages are held (by setup.sh and on the image) so apt can't replace them,
    but dpkg also refuses to upgrade held packages - so updating a flashed Rock to a new
    kernel-N release failed. setup.sh is the one place meant to update them.
2026-10-09 Docs reorganised (short README + docs/); hotspot pinned to WPA2/AES
    - README cut from 754 to ~120 lines: what it is, set up the Rock, set up the Mac, a
    game day, links, status (calibration no longer wrongly listed as a placeholder).
    The detail moves, mostly verbatim, to docs/rock.md, docs/calibration.md,
    docs/stitching.md and docs/editing.md; references repointed.
    - camera-network: create the hotspot as WPA2 (RSN) with CCMP only and PMF off, as
    NetworkManager's own hotspot command does. With the defaults (WPA/WPA2, TKIP/CCMP,
    PMF default) an iPhone/Mac refused to join VeeryCam at all; verified on the Rock.
2026-10-10 Hardware half of the project: hardware/ with parts list, genlock, assembly
    - hardware/README.md: the parts list (M12-mount Pi HQ cameras, CIL391 lenses, ROCK 5T,
    Radxa heatsink 6240B, AC008 FPC cables, Noctua fans, NVMe 500 GB+, housing, inserts;
    power: USB-C PD power bank + PD-to-DC cable set to 15 V), the XVS genlock wire and why
    it decided the camera module, design choices and assembly. The housing models move
    from 3d-housing-model/ to hardware/housing/.
    - README: the project is hardware + software; what the image is (Radxa's image + camera
    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
    [Rock Housing - Bottom - PRINT ORIENTED.stl, Rock Housing - Bottom.3mf, Rock Housing - Bottom.stl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]
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
